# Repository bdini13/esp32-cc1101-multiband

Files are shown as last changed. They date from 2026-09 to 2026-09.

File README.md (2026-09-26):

# ESP32 + CC1101 Multiband

A custom USB-C development board combining an **ESP32-WROOM-32E-N8** with an
integrated **CC1101** sub-GHz radio, software-selected RF paths, and a vertical
SMA antenna connector at the opposite end from USB-C.

**Rev A3 · Fully connected review candidate · Not approved to manufacture or sell**

The aim is to replace a separate ESP32 board, CC1101 breakout and jumper wires
with one purpose-built PCB. The first intended build is **five assembled
engineering prototypes**, after the pre-order checks are complete. Possible
product sales are a future option, not a launch announcement.

## Current design

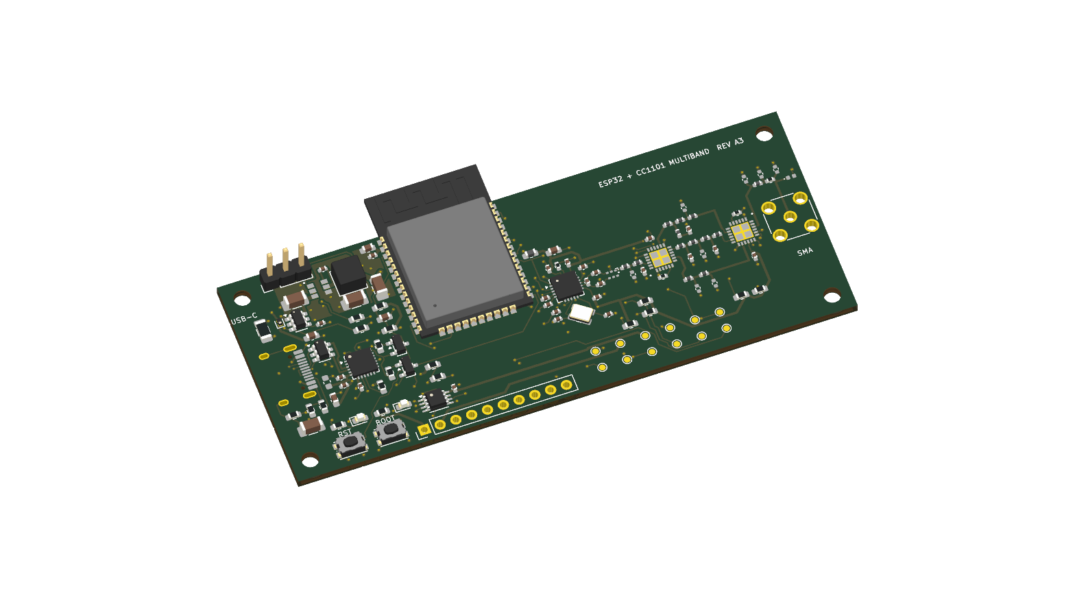
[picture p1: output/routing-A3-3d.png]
A3 angled KiCad routed-board render, USB area left and SMA footprint right


*KiCad design render—not a photograph of a built board. USB, SMA and some
RF parts lack complete 3D bodies. Their absence in the image does not mean
they were removed from the design.*

<details>
<summary>Top view and experimental routing</summary>

A3 top-copper routing candidate

*The routing image is a separate experimental candidate, not the main placement
file or a fabrication package. Bottom and inner routes are not shown here.*

</details>

[Schematic SVG](output/svg-A3/esp32-cc1101-multiband.svg) ·
[Latest design report](reports/autonomous-refinement-A3-2026-09-26.md) ·
[Draft BOM](hardware/bom-draft.csv) · [Roadmap](ROADMAP.md)

Latest work: A3 replaces the power supply and RF switches, completes routed
connectivity, adds safe RF boot sequencing and proposes all populated parts.
See [engineering decisions and first-power instructions](docs/06-A3-prototype-engineering.md)
and the [pre-order blocker report](reports/preflight-A3.json). The crystal was
relocated and rerouted: all 180 artifact checks and six route screens now pass.
Independent/supplier reviews remain pending. No hardware has been tested.
Do not order historical A2 files.

## Building blocks and design inputs

### ESP32-WROOM-32E-N8 — controller and 2.4 GHz connectivity

<a href="https://www.espressif.com/en/products/modules/esp-">
  Manufacturer reference image of the stock ESP32-WROOM-32E module
</a>

*Stock module reference image: Espressif, linked from the manufacturer's site.
This is not a photo of the custom board or a guarantee of the N8 marking.*

The actual component is an Espressif module, not an entire stock development
board soldered onto another PCB. The selected N8 variant has 8 MB flash; its
ESP32 provides a dual-core processor, 2.4 GHz Wi-Fi and Bluetooth. Its PCB
antenna is separate from the sub-GHz SMA path. The antenna section extends
beyond the custom base board to preserve its keepout.
[Module datasheet](https://documentation.espressif.com/esp32-wroom-32e_esp32-wroom-32ue_datasheet_en.html).

Power/programming uses ESP32 development-board conventions: USB-to-UART,
automatic reset/boot control and manual BOOT/RESET buttons. This is not a
pin-compatible clone of a particular commercial DevKit.
[Espressif ESP32-DevKitC reference](https://docs.espressif.com/projects/esp-dev-kits/en/latest/esp32/esp32-devkitc/user_guide.html).

### Texas Instruments CC1101 — sub-GHz transceiver

<a href="https://www.ti.com/product/CC1101">
  Texas Instruments representative RGP 20-pin QFN package image for CC1101
</a>

*Representative package image: Texas Instruments. This is the IC package,
not a complete CC1101 antenna module; package markings may differ.*

The PCB integrates **CC1101RGPR** directly, with its crystal, bypass capacitors,
balun, switches and matching/filter components. TI specifies tuning ranges
of 300–348, 387–464 and 779–928 MHz. That does **not** make every frequency or
antenna equally usable or establish this board's RF performance.
[CC1101 product information and datasheet](https://www.ti.com/product/CC1101).

The separate [Amazon CC1101 module](https://a.co/d/01gplHzS) supplied by the
owner was a functional starting point. Its exact internal circuit and advertised
four-band performance have not been independently verified here. The switched
RF topology and initial component values also reference the
[M5Stack Cap CC1101 schematic](https://docs.m5stack.com/en/cap/Cap_CC1101).
This is a different implementation, not an endorsed M5Stack product.

### Supporting parts currently selected

| Function | Current design choice |
|---|---|
| USB-C | HRO TYPE-C-31-M-12, USB 2.0 connection |
| USB-to-UART | Silicon Labs CP2102N-A02-GQFN24 |
| 3.3 V regulator | AP63203WU-7 buck, XAL4030 4.7 uH inductor |
| USB startup / UART isolation | TPS22918, SN74LVC2G125; J4 ships unjumpered |
| Radio reference | Abracon ABM8, 26 MHz; load requires validation |
| RF selection | Two pSemi PE42442A-Z SP4T switches; three paths used |
| RF balun | B0310J50100AHF |
| Antenna connector | Amphenol 132134, vertical standard SMA female, 50 ohm |

See [third-party notices](THIRD_PARTY_NOTICES.md) for provenance, image credits
and license boundaries. Parts remain subject to sourcing, footprint and assembly
approval; the BOM is not an approved shopping list.

## Planned capabilities and features

| Feature | Planned behavior | Status |
|---|---|---|
| Four target bands | 315 / 433 / 868 / 915 MHz, one selected at a time | Not RF-validated |
| Software band switching | GPIO-operated RF switches; no DIP switches | Circuit present; firmware isolation only |
| Three RF branches | Dedicated 315 and 433 paths; shared 868/915 path | Matching, loss and isolation unmeasured |
| Single sub-GHz SMA | Vertical connector opposite USB-C | Placed; mechanical approval pending |
| USB-C power/programming | 5 V input, USB-to-UART flashing/logging | Captured; not bench-tested |
| Wi-Fi / Bluetooth | Available through the ESP32 module | Application integration planned |
| Developer controls | BOOT, RESET, LEDs and test pads | Included in draft |
| Expansion | Optional DNP 10-pin header | Included in draft |
| PCB | 90 × 36 mm base, four layers, nominal 1.6 mm | Stackup/impedance release pending |
| Safe bring-up | RF paths isolated; no transmit command | Implemented in initial firmware |

Band switching changes the **hardware path**. Future firmware must also set the
radio frequency/modem registers and operating limits. One CC1101 cannot listen
on all four bands simultaneously. Use an antenna suitable for the selected
band; a shared SMA does not imply a universal antenna.

There is no native USB, USB-PD, battery charger, finished RF application or
guaranteed protocol compatibility in this revision.

## What has actually been checked?

Snapshot: **2026-09-26**, KiCad 10.0.6. Design-file checks, not lab results.

| Check | Result |
|---|---|
| Schematic ERC | 0 reported violations |
| Main placement seed DRC | 0 violations; 283 unconnected items (not the routed board) |
| Targeted artifact checks | **180 / 180 passing** on refined candidate / explicit seed checks |
| Added route screens | **6 / 6 passing**; oscillator routing, cross-layer clearance and modeled DC drops |
| Separate A3 routed candidate DRC | **0 violations; 0 unconnected items** |
| Fresh schematic / routed PCB comparison | Every numbered pad net, value and footprint name matches |
| Layer constraints | No signal traces on In1; RF/clock top-only; documented USB crossover |
| Candidate power routing | Main rails explicitly routed; 60 narrower branch/neck segments listed; critical copper paths quantitatively screened |
| Parts selection | **94 / 94** populated positions have proposed exact parts; sourcing unapproved |
| Physical boards tested | **None** |

Zero reported violations does not prove working or compliant hardware. A3's
power redesign addresses the earlier LDO heat problem and the new switches
cover the target bands in their specified frequency range. Actual power
sequencing, temperature, impedance, matching and crystal startup/frequency
remain unmeasured. C21 and U5 contain in-pad vias requiring filled/capped
processing; supplier DFM confirmation is mandatory. USB power must be
configured before fitting J4, and full combined Wi-Fi/radio load is not approved.

[Raw reports](reports/) · [Verification checklist](docs/04-verification-plan.md) ·
[Power, routing and RF validation plan](docs/06-A3-prototype-engineering.md)

## Roadmap

1. **Design capture — substantially complete:** schematic, placement, draft
   BOM, local footprints, bring-up firmware and automated checks.
2. **Prototype review — in progress:** routed connectivity and proposed parts
   complete; crystal, power, mechanical, supplier and independent review open.
3. **Five-board build — not ordered:** reviewed fabrication and assembly files,
   then separately approved prototype procurement.
4. **Bench and RF tuning — not started:** power/temperature, USB, crystal,
   per-band matching, harmonics and receive performance.
5. **Firmware/application — planned:** validated receive-first operation,
   controlled band changes and deliberately configured regional limits.
6. **Possible product — undecided:** hardware revision, compliance, enclosure,
   test fixtures, sourcing, support and commercial terms.

The [detailed roadmap](ROADMAP.md) uses acceptance criteria, not promised dates.
There is no release date, sales price, preorder or claim of certification.

## Open the project

Open `hardware/esp32-cc1101-multiband.kicad_pro` in **KiCad 10** for the main
placement seed and schematic. Open `hardware/A3-routing-candidate.kicad_pro`
separately for the unapproved routing experiment. Do not order either one.

Python generators are the editable source for this checkpoint. **Regenerating
placement overwrites the generated board; preserve manual routing first.**
See [rebuild instructions](hardware/REBUILD.md) and
[firmware instructions](firmware/bringup/README.md).

Initial firmware resets the CC1101, checks repeated PARTNUM/VERSION reads and
stable IDLE state, and logs explicit failures. It does not configure a receiver
or transmitter and has not run on physical hardware. Passing digital diagnostics
is not proof of authenticity or RF qualification.

## AI disclosure

This project is developed with substantial assistance from **OpenAI Codex**
under the owner's direction. AI assisted with component research, schematic/PCB
generators, footprints, experimental routing, firmware, documentation and review.
Design images are KiCad renders/exports, not AI-generated product photographs.

AI output and automated checks can contain errors. They are not independent
engineering approval, bench validation or regulatory certification. No physical
prototype has been completed. Qualified human electrical/RF review remains a
release gate. See the [full AI disclosure](AI_DISCLOSURE.md).

## Licensing, commercial plans and safety

This initial publication uses the **[Public Review License](LICENSE)**:
non-commercial study/private evaluation is permitted; manufacturing, product
sales and other uses beyond its limited permissions require written permission.
Commercial rights are reserved while the owner's plans are undecided. This is
**source-available, not open-source/open hardware**. Third-party terms are
separate; see [notices](THIRD_PARTY_NOTICES.md). Obtain legal advice before
relying on the custom license for a commercial launch.

Use only with equipment and signals you own or are authorized to test. Tunable
frequencies are not automatically permitted transmit frequencies. Final use and
sale require applicable RF, EMC, product-safety and other compliance work. This
prototype is not for safety-critical applications. No manufacturer named here
endorses the project.

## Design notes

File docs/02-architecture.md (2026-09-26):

# A3 architecture

Current circuit source: `hardware/generate_schematic.py`. Detailed decisions,
sources and limits: [A3 engineering notes](06-A3-prototype-engineering.md).
Historical A1/A2 files are not interchangeable with A3.

## Power and programming

USB-C 5 V passes through a 750 mA PTC and transient protection. The CP2102N
internal regulator powers only its USB-side logic (`+3V3_USB`). Its SUSPENDb
output, via an initially unfitted J4 shunt, enables TPS22918. That switch
soft-starts the AP63203 3.3 V buck and the ESP32/radio supply. SN74LVC2G125
isolates the UART while the main rail is off. Manual BOOT/RESET and the
two-transistor DTR/RTS auto-programming circuit are retained.

J4 ships open. Configure/read back a bus-powered 500 mA USB descriptor before
using AUTO (1–2). EXT (2–3) needs a separately verified regulated 5 V source.
There is no USB-PD negotiation, battery support or external-power source ORing.
The buck's IC rating is not a board/USB current rating. High combined Wi-Fi/RF
loads are not approved. USB suspend shuts down the main rail.

The RF rail passes through a ferrite and local bypass capacitors. CC1101
DGUARD is supplied, not grounded. A 26 MHz four-pad crystal provides its clock;
load capacitance and oscillator startup/frequency need bench verification.
The refined diagonal placement meets both original distance targets and
reduces the longest clock route to approximately 3.99 mm.

## Radio path

CC1101 differential RF → broadband balun → PE42442 input selector → one of
three filter branches → PE42442 output selector → tuning network → vertical
standard SMA female. Branches target 315, 433 and shared 868/915 MHz.

Both switches use 10 kohm external control pullups and boot in 111 isolation.
Their fourth RF ports are terminated in 49.9 ohm. U4's outer branches are
reversed physically, with independent GPIO controls; see the
[pin map](03-pin-map.md). Firmware currently performs digital checks only,
keeps every path isolated, and provides no RX/TX command.

Reference-derived matching values are starting points. The CC1101 tuning
range alone does not establish a four-band antenna match, sensitivity, range
or emissions compliance. Prototype RF tuning and measurement are required.

## Mechanical and layout

90 × 36 mm four-layer base, nominal 1.6 mm. USB-C opens at the left end;
SMA is vertical at the right. The ESP32-WROOM-32E-N8 antenna overhangs the
top edge. Proposed L2 is uninterrupted ground; no signal routing is allowed
there. Main RF and oscillator traces stay on top. USB has a short bottom-side
connector crossover. Actual impedance requires fabricator confirmation.

Two in-pad vias require filled/capped processing, not ordinary open drills:
C21 at (46.5,18.9) mm and U5 exposed pad at (16,19.4) mm. All coordinates
are KiCad board coordinates. Supplier review must also inspect nearby vias,
paste coverage, component orientation and connector fit.

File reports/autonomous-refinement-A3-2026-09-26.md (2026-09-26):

# A3 autonomous layout refinement — 2026-09-26

The remaining crystal placement failure was resolved in the routed candidate,
without weakening its 3.5 mm limit. No part, pin assignment, RF filter value,
firmware operating mode or licensing term changed. No board was ordered.

## What changed

Y1 moved to (50.2,23.23) mm and -37.5 degrees. C31/C32 moved outward;
clock, ground, power and nearby digital traces were rebuilt. Both clocks
remain top-side and via-free. The earlier board is preserved in
`hardware/routing/A3-before-crystal-refinement.kicad_pcb`, with a source-hash
guard in the refinement script. The main placement/critical-route files remain
upstream seeds; the final routed candidate is the current layout authority.

| Metric | Before | Refined candidate |
|---|---:|---:|
| U2.8 to Y1.1 straight-line distance | 2.195 mm | 3.468 mm |
| U2.10 to Y1.3 straight-line distance | 4.478 mm | 3.479 mm |
| Q1 routed pin-center to crystal-center length | 2.538 mm | 4.299 mm |
| Q2 routed pin-center to crystal-center length | 6.887 mm | 3.994 mm |
| Longest clock route | 6.887 mm | 4.299 mm |
| Artifact checks | 179/180 | 180/180 |
| Added route screens | 4/6 (retrospective) | 6/6 |

This tradeoff lengthens Q1 while reducing Q2 and the total clock-route length.
The near-diagonal crystal is deliberate, not an assembly rotation error; the
assembler must honor its actual angle. Existing courtyard and clearance rules
were retained. Crystal load values remain starting values, not a measured tune.

## New checks beyond native DRC

TI advises keeping sharp-edged digital routing away from the oscillator input
and from beneath the Q1 crystal pad. The new screen projects digital traces
and vias from **every copper layer** onto the full Q1 rectangular pad envelope;
it conservatively ignores rounded corners and does not waive the screen
because a ground plane lies between layers.
[CC1101 datasheet](https://www.ti.com/lit/ds/symlink/cc1101.pdf).

The first trial caught CSn/GDO2 under this envelope. They and a nearby RF
selector route were moved. Minimum projected clearance is now **0.2079 mm**,
against a project screen of 0.20 mm. New tests deliberately inject a bottom
trace under the pad and verify detection. This is a geometry screen, not a
coupling/noise simulation. Other oscillator/RF review and bench tests remain.

The route model also follows actual trace/via connectivity to estimate DC
resistance. It assumes copper at 80 C, 80% of target layer copper thickness,
and 20 um via plating; each layer transition is charged a full 1.6 mm barrel.
These are explicit modeling assumptions, not supplier guarantees.

| Copper path | Independent screening load | Modeled drop |
|---|---:|---:|
| Buck output L1.2 → ESP32 supply | 0.5 A | 7.423 mV |
| USB A4 → fuse | 0.5 A | 14.331 mV |
| USB A9 → fuse | 0.5 A | 20.464 mV |
| Fuse → main load switch | 0.5 A | 4.667 mV |
| Load switch → buck input | 0.5 A | 2.506 mV |
| RF bead output → output RF switch | 0.1 A | 13.316 mV |

The model omits components, contacts/pad spreading, cable and ground-return
resistance. It follows the least-resistance single path, ignoring parallel
paths. It is not a thermal, ampacity, transient, USB-compliance or RF-noise
analysis. Loads in different rows must not be added and presented as an
approved simultaneous operating mode. See all 14 paths and six project screens
in [the current model](route-margins-A3.json) and the
[retrospective baseline](route-margins-A3-before-crystal-refinement.json).

## Verification and remaining boundary

- Native candidate DRC: **0 violations / 0 unconnected items**.
- Fresh schematic/PCB parity: passes; schematic connectivity is unchanged.
- Artifact audit: **180/180**, now checks the final routed geometry; only the
  two initial-stitching checks explicitly use the placement seed.
- Route screens: **6/6**. Seven new geometry/resistance/fault-injection tests pass.
- Eight preflight tests pass. Fresh preflight reruns route metrics and hashes
  generator/check code plus firmware sources, as well as hardware artifacts.
- Existing 17 diagnostic cases, RF-boot tests and connectivity fault tests
  are rerun; firmware has not been flashed or tested on hardware.

Preflight still requires six unsigned independent/supplier review categories.
Filled/capped C21 and U5 vias remain necessary. Matching, oscillator startup,
frequency accuracy, USB sequencing, thermal behavior and RF performance are
unmeasured. No human review was marked approved by the agent, and no
fabrication package or purchase order was created.

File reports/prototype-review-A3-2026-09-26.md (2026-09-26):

# A3 prototype-review checkpoint — 2026-09-26

**Historical pre-refinement snapshot.** The crystal failure below has since
been resolved without changing its threshold. See the
[current refinement report](autonomous-refinement-A3-2026-09-26.md).

**Fully connected review candidate, not an approved order or proven radio.**
The owner's five-board prototype goal is unchanged. No hardware, quote, order,
human signature or measurement is represented by this checkpoint.

## Problems addressed

- Replaced the heat-constrained LDO with AP63203, a rated 4.7 uH inductor and
  higher-voltage/larger MLCCs selected after inspecting DC-bias curves.
- Added USB-side independent power, enumeration-controlled TPS22918 startup,
  J4 commissioning control and powered-off-protected UART buffers. Documented
  the USB current limitation instead of implying a buck negotiates power.
- Replaced the previous low-band-limited RF switches with PE42442 SP4Ts;
  checked manufacturer pin/land drawings, terminated unused RF4 ports and
  gave U4 independent selectors to avoid RF crossings.
- Corrected safe boot to five HIGH controls with 10 kohm pullups. Added
  preload/disable-order tests; transmit and receive commands remain absent.
- Explicitly routed RF, oscillator, USB, converter and main power before
  digital routing. Finished the remaining nets without suppressing DRC errors.
- Proposed exact parts for all 94 populated positions, plus a separate loose
  power-arm shunt accessory. There are 117 schematic footprints / 121 PCB
  footprints including four mounting holes; DNP parts and bare pads are not
  populated BOM purchases.
- Added fresh schematic/PCB comparison and fault-injected tests that reject
  wrong net, value, footprint name and missing component. A clean stale
  netlist is not accepted as the only connectivity evidence.

## Evidence

| Check | Result |
|---|---|
| Fresh schematic ERC | 0 violations |
| Routed A3 native DRC | 0 violations / 0 unconnected items |
| Fresh schematic to candidate comparison | PASS |
| Placement-seed native DRC | 0 violations / 283 unconnected items, intentionally unrouted |
| Artifact audit | 179/180; one crystal placement screening failure retained |
| Routing-layer constraints | 0 violations; no In1 signal tracks |
| Digital diagnostic tests | 17 fault-injection scenarios pass |
| RF boot tests | Pin map, preload order, disable-first and re-isolation pass |
| Preflight tests | 7 pass |
| Connectivity fault-injection tests | 4 malformed temporary boards rejected |
| ESP32 firmware build | PASS; 275645 bytes flash / 21576 bytes RAM |
| Physical boards tested | None |

The build used espressif32 7.1.3, Arduino framework
4.20017.260907+sha.dcc1105b, esptool 2.41100.260830 and Xtensa toolchain
8.4.0+2021r2-patch5. Project settings explicitly select 8 MB flash and
default_8MB partitions; the generic platform banner still says 4 MB.

KiCad top-copper, ground-plane, schematic and 3D exports were visually
inspected. The ground plane has no routed signals and appears continuous
beneath the circuitry; that is not an EMC/impedance certification. Missing
USB/SMA/custom-IC 3D bodies are disclosed in the README.

## Open items, with concrete closure criteria

1. **Crystal:** U2.10 to Y1.3 is 4.478 mm straight-line versus the retained
   3.5 mm screening target. The route is approximately 6.888 mm, plus its
   load-cap branch (whole net 8.142 mm). Q1 whole-net copper is 4.545 mm.
   The 3.5 mm limit is a project screening target, not a quoted TI maximum.
   An RF reviewer must assess relocation/clock loading before release; measure
   cold starts, frequency and supply/temperature sensitivity on the prototype.
   The check has deliberately NOT been weakened or silently waived.
2. **Power:** main paths are explicitly routed, but 62 branch/neck segments
   below 0.40 mm remain listed for current/voltage-drop review. Confirm USB
   configuration and J4 procedure, suspend/resume, back-power leakage, load
   steps, fuse drop and converter temperature. The full combined Wi-Fi/radio
   load can exceed 500 mA input at low cable-end voltage; it is not approved.
3. **RF:** approve matching/layout for prototype tuning, then measure each
   selected path with a VNA and conducted receive/spectral equipment. The
   switches' specified frequency coverage does not validate the whole board.
   Current firmware tests digital access only, not usable multiband RX/TX.
4. **Fabrication/assembly:** confirm exact stackup, RF/USB impedance, all
   small vias and pad-adjacent drills. C21.1 (46.5,18.9 mm) and U5 exposed
   ground pad (16,19.4 mm) require resin-filled/copper-capped vias. Confirm
   paste coverage, footprints, USB/SMA fit and real part availability.
5. **Independent review:** a qualified electrical/RF reviewer must approve
   the exact candidate hashes and documented prototype risks. No AI-generated
   result substitutes for their review or the subsequent bench tests.

See [fresh preflight](preflight-A3.json), [routing audit](routing-audit-A3.json),
[engineering calculations](engineering-budget-A3.json), and the
[detailed commissioning/acceptance plan](../docs/06-A3-prototype-engineering.md).
Preflight remains BLOCKED. No fabrication package was generated and no order
was placed. A1/A2 artifacts are historical; do not mix their firmware or parts
with A3. The existing project license is unchanged.

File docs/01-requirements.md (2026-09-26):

# Rev A Requirements

Status: initial requirements captured 2026-09-20; updated for A3 2026-09-26.
These are target requirements, not assertions that the draft already satisfies them.

## Functional requirements

1. Use an ESP32-WROOM-32E module with 8 MB flash.
2. Integrate one TI CC1101 transceiver directly on the main PCB.
3. Support software selection of 315, 433, and 868/915 MHz RF matching paths.
4. Use one standard 50-ohm SMA female antenna connector.
5. Place the SMA connector vertically at the short end opposite USB-C.
6. Provide USB-C power, serial programming, logging, and automatic bootloader
   entry.
7. Provide physical RESET and BOOT buttons.
8. Provide a power LED and a firmware-controlled status LED.
9. Expose spare GPIO, 3V3, 5V, and ground on a 2.54 mm expansion header.
10. Include accessible test points for all power rails, UART, SPI, CC1101 GDO
    signals, and RF-switch control signals.

## Electrical requirements

- USB input: nominal 5 V.
- Logic and radio rail: 3.3 V.
- A3 uses AP63203 fixed 3.3 V buck, rated 2 A as an IC, not as a board.
  Actual board current is limited by USB source capability, voltage drop,
  fuse derating and measured thermal behavior; full simultaneous Wi-Fi/RF
  load is not yet approved. Configure the USB descriptor with J4 open first.
- USB-C CC1 and CC2: independent 5.1 kohm pull-down resistors.
- USB D+ and D-: ESD protected and routed as a differential pair.
- ESP32 EN: RC power-on reset plus USB-UART automatic reset control.
- CC1101: dedicated local decoupling at every supply pin.
- RF switches: five 10 kohm pullups select the isolated `111` state during boot;
  firmware must keep the CC1101 idle during path changes.

## Mechanical requirements

- Nominal board outline: 90.0 mm x 36.0 mm.
- Four-layer stackup with uninterrupted internal ground plane.
- USB-C centered on one 36 mm edge.
- Straight through-hole SMA centered on the opposite 36 mm edge.
- Four M2.5 mounting holes, final coordinates subject to component clearance.
- ESP32 module PCB antenna located at a board edge with the Espressif keepout
  observed on every copper layer.
- A1 placement: module antenna tip projects 6.45 mm beyond the base PCB.
  Allow at least 42.45 mm total width before enclosure/RF clearances.
- Maintain maximum practical separation between the ESP32 antenna and the
  CC1101 RF section/SMA connector.

## User-facing behavior

- Power-up state: CC1101 idle, transmit disabled.
- Firmware band API: `315`, `433`, `868`, or `915`.
- Selecting a band first idles the radio, then changes the RF switches, waits
  for settling, loads band-specific CC1101 registers, and calibrates.
- A3 switch state `111` is the all-paths-isolated safe state; `000` selects RF4.
- Transmit operations require an explicit region profile and compatible
  antenna confirmation in production firmware.

## Prototype quantity

- Five assembled Rev A boards.
- Optional spare boards and band-appropriate antennas need a separately
  approved quote; no purchase is authorized by this requirements document.

## Explicitly out of scope for Rev A

- Battery charging or battery connector.
- Display, keypad, audio, NFC, SD card, or external power amplifier.
- Weatherproofing or production enclosure.
- FCC/CE certification.
- Simultaneous operation on multiple sub-GHz bands.

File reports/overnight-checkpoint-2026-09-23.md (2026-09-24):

# A2 overnight checkpoint — 2026-09-23

Status: saved engineering progress, **not ready for an order**. No PCB topology,
placement or routing was changed in this checkpoint. A2 images remain current.

## Completed

- Replaced the firmware's permissive identity check, which accepted an all-zero
  SPI response, with repeated exact identity checks and stable IDLE detection.
- Added bounded waits, distinct failure reporting, transaction cleanup, the TI
  manual-reset preamble, and a restricted API with no RX/TX/path-selection entry.
- Added 17 host fault-injection scenarios and six pre-order-check unit tests.
  All pass. Host tests do not validate GPIO waveforms or physical hardware.
- Successfully built the ESP32 firmware: 21,576 bytes RAM, 275,569 bytes flash.
- Re-ran the design audit: 115/115 pass. Fresh native KiCad checks: ERC zero
  violations; candidate DRC zero violations and **23 unconnected items**.
- Added a fresh-check preflight command, explicit pending review records and
  input SHA-256 fingerprints. It reports **BLOCKED**, as intended.
- Corrected the pin-map claim that GPIO4 was a boot-strapping GPIO.

Build environment: PlatformIO espressif32 7.1.3, Arduino framework
4.20017.260907+sha.dcc1105b, Xtensa toolchain 8.4.0+2021r2-patch5,
esptool package 2.41100.260830. Platform version pinned; no device flashed.

## Power replacement screening

AP63203WU-7 is a candidate, **not substituted into A2**. It is a fixed-3.3 V
buck with a 3.8–32 V input range. The manufacturer's starting circuit uses a
3.9 uH inductor, 10 uF input capacitance, two 22 uF output capacitors and a
100 nF bootstrap capacitor. TSOT26 pins are FB1, EN2, VIN3, GND4, SW5, BST6.
Its switching behavior requires a new hot-loop layout, shielded-inductor
selection, capacitor derating, noise review and transient testing. It does not
solve USB input-current permission. The PDF skill guided visual inspection of
manufacturer pin/ordering drawings before deciding against an unverified swap.
[Diodes datasheet](https://www.diodes.com/assets/Datasheets/AP63200-AP63201-AP63203-AP63205.pdf).

## RF replacement screening

PE42430 is another candidate, **not a drop-in replacement**. Its specified RF
range extends down to 100 MHz, but it has three control inputs and derives
power from them; control-high minimum is 3.0 V. That is not a verified direct
ESP32 GPIO interface. Its pinout, ground paddle, startup isolation, logic drive
margin and routing would all need redesign/review. Retaining the existing
switch in the saved draft does not resolve its low-band performance risk.
Visual inspection of the manufacturer's pinout and operating-range table
prevented treating it as an interchangeable eight-pin part.
[pSemi datasheet](https://psemi.com/pdf/datasheets/pe42430ds.pdf).

## Reproduce the order-blocker check

```sh
python3 tools/test_preflight.py
python3 tools/preflight.py --kicad-cli kicad-cli --output reports/preflight-A2.json
```

The last command intentionally exits **2** when blocked; 1 indicates execution
failure. It runs new ERC and candidate DRC, then checks BOM selection and six
review records. Even with all gates closed, it only reports that separate owner
order approval is needed. It cannot place orders or export fabrication files.
The candidate has a separate basename, so schematic parity is not automatically
checked by this command; independent connectivity review remains mandatory.
Review records are declarations, not authenticated engineering sign-offs.

## Remaining before the five-board prototype order

1. Choose/review power and low-band RF solutions; then revise the circuit/layout.
2. Finish critical routing and the 23 connections; review 35 narrow power
   segments, USB pair geometry, RF impedance and return paths.
3. Select the remaining 18 populated BOM positions and approve sourcing/assembly.
4. Complete mechanical and independent electrical/RF review, then obtain a quote
   and separate purchase approval. Bench/RF validation follows the prototype build.

See the [machine-readable fresh-check snapshot](preflight-A2.json) and
[roadmap](../ROADMAP.md). There are still no physical measurements or built boards.

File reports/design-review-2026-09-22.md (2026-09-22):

# PCB design review — 2026-09-22

Disposition: **requires schematic and placement corrections before routing or manufacture.**

Reviewed the saved KiCad schematic, XML netlist, PCB pad assignments, generator
sources, BOM, custom RF footprints, and existing placement renders. Reran ERC
and DRC against the saved files without regenerating or modifying the design.
Manufacturer PDF drawings were checked visually where available, including the
balun outline and the previously captured M5Stack reference schematic.

## Confirmed electrical and mechanical defects

### 1. P1 — CC1101 DGUARD is connected to ground

`hardware/generate_schematic.py:287` assigns U2 pin 18 to GND. The saved netlist
and PCB both contain that connection. Pin 18 is DGUARD, a supply input, not a
ground pin. TI's pin table identifies it as a power-supply connection; the
M5Stack reference used for this project connects it to 3.3 V with the other
CC1101 supply pins. Correct to the appropriate RF supply and review all supply
connections and bypass capacitors. Functional radio operation cannot be assumed
with this pin grounded.

Source: [TI CC1101 datasheet, Table 19 and application circuits](https://www.ti.com/lit/ds/symlink/cc1101.pdf).

### 2. P1 — Balun footprint pad numbering is mirrored

`hardware/lib/esp32_cc1101.pretty/TTM_B0310J50100AHF.kicad_mod:24` places
1-2-3 across the upper row and 6-5-4 across the lower row. This copies the
manufacturer's explicitly labeled BOTTOM VIEW into a front-side PCB footprint.
With the same vertical orientation, the top view must have 3-2-1 across the
upper row and 4-5-6 across the lower row. The physical orientation marker must
also agree with the top view. Rotation alone does not correct a reflection.

Rebuild the footprint from a top-view projection and recheck the assembly
orientation. As drawn, the grounded pad 2 and unconnected pad 5 prevent a simple
180-degree rotation of the real part from restoring the intended connections.

Source: [TTM B0310J50100AHF Rev F, page 1 outline and pin table](https://cdn.ttm.com/repository/products/wireless-xinger/balun-transformers/B0310J50100AHF/B0310J50100AHF.pdf).

### 3. P1 — USB-C receptacle faces into the board

`hardware/generate_pcb.py:62` places J1 at (4.8, 18.0), rotation +90 degrees.
The installed KiCad USB4105 footprint marks its intended PCB edge at local
y=+3.675 mm. On the saved board that line is at x=8.475 mm, while the board's
left edge is x=0. The solder tails lie near x=1.12 mm. Thus the mating opening
faces the electronics instead of the outside edge. Rotate and reposition the
connector with its annotated mating edge aligned to the left board edge, then
redo USB protection placement and mechanical clearance.

Evidence: saved PCB geometry and the installed
`Connector_USB:USB_C_Receptacle_GCT_USB4105-xx-A_16P_TopMnt_Horizontal`
footprint's `PCB Edge` annotation. The previous render approval missed this.

### 4. P1 — CP2102N VBUS sensing bypasses the required divider

`hardware/generate_schematic.py:157` connects U5 pin 8 directly to the protected
5 V rail. Silicon Labs requires a resistor divider or equivalent for this
sense input in both bus-powered and self-powered configurations, including
when VIO is not yet powered. Its reference circuit uses 22.1 kohm above the
sense node and 47.5 kohm to ground. Pin 7 VREGIN is a separate power input;
do not apply the divider to the power input.

The power arrangement also needs a complete bypass and sequencing review:
VIO uses the external 3.3 V supply while VDD uses the internal regulator. C3 is
the only capacitor on VDD, and C4's VIO pad is 7.33 mm from the IC pad. Check
the manufacturer's per-power-pin capacitor requirements and VIO <= VDD limit.

Source: [Silicon Labs CP2102N datasheet, sections 2.1, 2.3 and Table 3.1](https://www.silabs.com/documents/public/data-sheets/cp2102n-datasheet.pdf).

### 5. P2 — Both indicator LEDs are reversed

`hardware/generate_schematic.py:247` and `:255` connect LED pin 1 to the
positive resistor node and pin 2 to ground. The embedded KiCad Device:LED
symbol defines pin 1 as K (cathode) and pin 2 as A (anode). Both LEDs are
therefore reverse-biased in their intended operating state and will not light
normally. Swap the electrical assignments and preserve a consistent assembly
polarity mark.

### 6. P1 — D2's proposed part does not fit its footprint

`hardware/bom-draft.csv:26` selects PESD5V0S1UL, but
`hardware/generate_schematic.py:122` assigns SOD-323. Nexperia specifies
DFN1006-2 / SOD882 for that exact part. Select a matching part/footprint pair.
Also use a symbol that communicates its unidirectional polarity; the current
generic D_TVS symbol has anonymous A1/A2 terminals.

Source: [Nexperia PESD5V0S1UL datasheet, pinning and ordering information](https://assets.nexperia.com/documents/data-sheet/PESD5V0S1UL.pdf).

## Placement and performance risks requiring revision

### 7. P1 — Radio bypass capacitors are remote; switch bypass capacitors are absent

The C21-C25 row in `hardware/generate_pcb.py:102` is arranged above U2 rather
than around its supply pins. For U2 pins 4/9/11/14/15, the nearest capacitor
supply-pad center is respectively 5.53/6.89/6.09/4.62/4.13 mm away. These are
straight-line distances before routing. Y1's pads are about 5.1 mm from the
oscillator pins, and the RBIAS resistor pad is 6.21 mm from its pin.

Neither U3 nor U4 has its own local bypass capacitor. Even C25 is 12.15 mm
from U3 VDD and 21.86 mm from U4 VDD. The captured M5Stack reference includes
one 100 nF capacitor at each switch. Add local switch bypassing and rebuild the
CC1101 placement around short supply, oscillator and ground-return paths.

The differential RF paths also need coordinated orientation: C40/BAL_N is
above C41/BAL_P, while the current balun puts BAL_N below BAL_P. Correcting the
mirrored footprint and arranging these parts together should precede routing.
The RF switches' common/branch pad locations must likewise drive placement.

Source: [TI CC1101 datasheet, sections 7.6 and 7.8](https://www.ti.com/lit/ds/symlink/cc1101.pdf).

### 8. P2 — ESP32 antenna placement does not match the earlier description

`hardware/generate_pcb.py:65` places the module at y=15.5 mm. Its antenna
section lies approximately between y=2.75 and y=8.94 mm, entirely over the
rectangular base PCB. It does not overhang the edge. The footprint keepout
being empty is helpful but does not establish RF performance or satisfy the
stated overhang arrangement. Move the module or design a suitable board cutout.

Source: [Espressif module placement guidance](https://docs.espressif.com/projects/esp-hardware-design-guidelines/en/latest/esp32/pcb-layout-design.html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).

### 9. P2 — Regulator thermal capability is unproven

U6 is the conventional DBV SOT-23-5 TLV75733P, not the exposed-pad package.
At an illustrative continuous 300 mA load, a 5 V to 3.3 V LDO dissipates
approximately 0.51 W. TI lists 231.1 C/W for DBV on its JEDEC board and
100.8 C/W in the EVM comparison, showing strong layout dependence. These are
screening figures, not predicted temperatures for this unrouted PCB.
Calculate the actual Wi-Fi/radio load profile and thermal margin before
accepting this package. Its 1 A current rating alone does not establish that
the board can dissipate the heat.

Source: [TI TLV757P datasheet, thermal information and power dissipation](https://www.ti.com/lit/ds/symlink/tlv757p.pdf).

## Verification results and limits

- Fresh ERC: 0 violations. U2 and the RF switches use generic connector
  symbols with passive pins, so ERC cannot meaningfully validate their power
  pin functions. Replace them with verified functional symbols.
- Fresh DRC: 4 hole-clearance **errors**, each 0.1944 mm actual versus
  the configured 0.2500 mm minimum, internal to J1. The earlier description
  called these warnings; the current project classifies them as errors.
- 206 unconnected items; 0 routed tracks/vias; 0 board-level copper zones.
  Exposed-pad holes exist inside footprints, but no ground plane connects them.
- No reported current pad shorts, general clearance violations or courtyard
  overlaps. This does not establish electrical correctness or RF suitability.
- Four copper layers and 1.6 mm overall thickness are specified, but no actual
  fabricator dielectric stackup or routed impedance-controlled geometry exists.
- J2 uses a vertical SMA footprint on the opposite end from J1, consistent with
  the intended connector arrangement. The orderable SMA part remains TBD.
- The documented GPIO truth table agrees with Infineon's table when SW0=V2
  and SW1=V1. This verifies logic, not the complete RF design or assembly.
- The BOM omits many ordinary resistors and capacitors and is not an assembly
  BOM. Exact RF part series, crystal and other unspecified items remain open.
- BGS13SN8's tabulated RF performance starts at 698 MHz; the listed broader
  frequency range alone is not a guarantee of 315/433 MHz performance. Verify
  those lower bands experimentally or obtain supporting characterization.

Source: [Infineon BGS13SN8 datasheet, Tables 4 and 9](https://www.infineon.com/assets/row/public/documents/24/49/infineon-bgs13sn8-datasheet-en.pdf).

## Recommended correction sequence

1. Correct DGUARD, balun footprint, LED polarity, CP2102N sensing/power circuit,
   and the D2 part/footprint mismatch; adopt functional IC symbols.
2. Reorient USB-C; resolve module antenna geometry; rebuild radio placement
   with local bypassing and short RF/oscillator paths.
3. Complete the exact BOM and thermal design, choose the fabrication stackup,
   and route power, ground, USB and RF with appropriate constraints.
4. Repeat netlist/pin audits, ERC, routed DRC and mechanical review before
   generating the five-board fabrication/assembly package.

Review only: schematic, PCB, generators and BOM were not changed by this review.

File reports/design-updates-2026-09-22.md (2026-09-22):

# Rev A1 correction record — 2026-09-22

Disposition: **review corrections implemented; still NOT FOR MANUFACTURE.**

The schematic, generated netlists, PCB, custom library, BOM inventory and renders
have been updated together. The previous review is retained unchanged as the
historical defect record. No Gerbers, purchase order or assembly release was made.

## Review findings and changes

| Finding | Implemented correction | Remaining qualification |
|---|---|---|
| CC1101 DGUARD grounded | U2.18 now +3V3_RF; dedicated C26 bypass | Power/ground routing and first-power measurements |
| Mirrored balun footprint | Top-view rows now 3–2–1 / 4–5–6; upper-right pin-1 mark | Physical part/tape orientation check before assembly |
| USB faces inward | J1 at (3.675,18) mm, −90°; recommended board-edge reference at x=0 | Connector-specific hole clearance and mechanical fit |
| CP2102N VBUS/power | 22.1k/47.5k sense divider; VIO/VDD/VREGIN on common external 3.3 V; 1k reset pull-up; local bypass pairs | Route and verify startup, USB enumeration and auto-reset |
| Reversed LEDs | D3/D4 pin 1 cathode to GND; pin 2 anode to resistor node | Assembly polarity and actual LED part selection |
| D2 package mismatch | PESD5V0S1UL now SOD-882, with explicit cathode/anode symbol | Confirm protection clamping and exact assembly package |
| Remote/missing decoupling | Repositioned C21–C25, crystal and bias resistor; added C26, C60/C61 and ESP32 C11/C12 | Short routed loops and ground stitching still required |
| ESP32 antenna over PCB | Module moved to y=6.30 mm; antenna tip y=−6.45 mm | Enclosure, nearby metal and RF testing |
| Small regulator thermal risk | AP7361C-33E-13 in SOT-223; grounded tab; preliminary heat spreading and eight vias | Load profile and measured thermal validation remain open |

Functional CC1101, BGS13SN8 and balun symbols replace generic connector symbols.
Pin types now provide more useful ERC, but ERC alone cannot identify every wrong
net assignment. The new `hardware/audit_design.py` checks generated artifacts for
the specific review regressions, rather than assuming the generator is correct.

Pin/source basis: [TI CC1101](https://www.ti.com/lit/ds/symlink/cc1101.pdf),
[Silicon Labs CP2102N](https://www.silabs.com/documents/public/data-sheets/cp2102n-datasheet.pdf),
[TTM balun](https://cdn.ttm.com/repository/products/wireless-xinger/balun-transformers/B0310J50100AHF/B0310J50100AHF.pdf),
[Nexperia D2](https://assets.nexperia.com/documents/data-sheet/PESD5V0S1UL.pdf).

## Placement and copper

- Base board remains 90 × 36 mm, four copper layers, nominal thickness 1.6 mm.
- Vertical SMA footprint remains at the end opposite USB-C. Exact SMA part
  approval is still pending. The installed matching 3D model is missing, so
  the renders show its lands, not the connector body. Custom RF package models
  are also absent; these renders are not a complete clearance certification.
- ESP32 overhang adds 6.45 mm to the base-board width before enclosure clearance.
  Its feed lies approximately 0.26 mm outside the board edge; keep the external
  antenna region clear of enclosure metal and wiring.
- U2 supply-pad to assigned bypass-pad distances are now 1.33–2.56 mm.
  Switch bypass distances are 1.68/1.26 mm. Crystal connections measure
  2.13/2.22 mm between pad centers. These are straight-line placement distances,
  **not** achieved routed lengths or evidence of RF performance.
- Initial In1.Cu/B.Cu GND zones and a front-side regulator heat-spreading zone
  are filled. Eight 0.60 mm diameter / 0.30 mm drill ground vias connect the
  regulator region. Final ground stitching, RF return paths, power routing,
  impedance geometry and layer-stackup definition are unfinished.

## Regulator screening — not a certified current limit

AP7361C-33E-13 uses IN/GND/OUT pins 1/2/3 and a grounded tab; the ER variant
has a different pinout. Its SOT-223 datasheet thermal figure is 110 °C/W on the
specified minimum-land test board. Our actual board resistance is unknown.
[Diodes AP7361C datasheet, pin descriptions and thermal information](https://www.diodes.com/datasheet/download/AP7361C.pdf).

Illustrative conservative screening assumes 5.25 V input, 3.267 V output
(−1%), and 40 °C ambient. Ignoring small quiescent losses:

| Continuous load | LDO dissipation | Estimated junction using 110 °C/W |
|---:|---:|---:|
| 300 mA | 0.595 W | 105 °C |
| 500 mA | 0.992 W | 149 °C |

These are calculations, not measurements. They show why even the larger
package does not justify claiming 500 mA continuous or 1 A board capacity.
Use 300 mA only as a provisional design-screening point, not an approved
operating rating. Validate Wi-Fi peaks, radio load, USB source capability,
fuse temperature derating, startup/inrush, capacitor effective capacitance and
worst-case ambient. A DC/DC redesign remains possible if measured load or
thermal margin requires it. No numerical thermal improvement is assumed from
the newly added copper without simulation or measurement.

## Fresh verification

- KiCad 10.0.6 schematic ERC: **0 violations**, `erc-corrected.json`.
- Targeted artifact audit: **107/107 pass**, `design-audit.json`.
- PCB DRC: **4 hole-clearance errors**, all internal to J1, 0.1944 mm actual
  versus configured 0.2500 mm minimum. No clearance rules were relaxed or
  violations excluded to obtain these results.
- **215 unconnected items**, zero routed signal/power tracks, eight standalone
  thermal vias and three board-level filled ground zones. Exposed-pad thermal
  holes embedded in footprints are additional and not counted as those vias.
- No reported pad shorts, ordinary copper-clearance violations, courtyard
  overlaps, edge-clearance violations or silkscreen collisions.
- BOM now covers all **103 schematic footprints**, including ordinary
  resistors/capacitors previously omitted. Four mounting-hole footprints are
  PCB-only mechanical features. DNPs/test pads are explicitly excluded from
  purchasing quantities; five-board counts do not include assembly attrition.
- Bring-up firmware: PlatformIO build succeeded (21,576 bytes RAM;
  274,913 bytes program usage reported). Firmware was not changed or flashed;
  this does not verify physical hardware or radio performance.
- Top/3D placement and schematic SVG exports refreshed and visually inspected.
  Schematic uses net labels; final routed review must trace complete net paths.

## Still required before five-board order

1. Select the fabricator's actual dielectric stackup and approved capabilities;
   resolve the connector clearance errors by supported geometry/rules or a
   verified connector change, then set controlled-impedance routing constraints.
2. Complete all power/signal/RF routing, decoupling ground loops and via fencing;
   rerun full DRC and independently review pin maps and RF topology.
3. Approve exact SMA, crystal, passive/RF series, fuse, ferrite, LEDs and other
   BOM options. The complete inventory is still **not** a procurement-ready BOM.
4. Complete the thermal/current design budget and protection review, and plan
   measured validation on the prototypes.
5. Review the unsupported low-band performance risk and arrange RF test access.
   The [BGS13SN8 datasheet](https://www.infineon.com/assets/row/public/documents/24/49/infineon-bgs13sn8-datasheet-en.pdf)
   does not supply the same tabulated RF guarantees at 315/433 MHz as at
   698 MHz and above. Matching values remain reference starting values.
6. Review fabrication/assembly outputs and physical connector orientation
   before authorizing the initial five assembled prototypes.

After prototypes exist, measure actual thermal/current behavior, characterize
315/433 MHz switch behavior and tune/test all RF branches before claiming
four-band performance. That validation is distinct from authorizing a
controlled prototype fabrication; it cannot be replaced by ERC or this audit.

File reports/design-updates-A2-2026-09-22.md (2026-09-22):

# A2 design updates — 2026-09-22

Disposition: **NOT ORDERABLE.** This pass fixes placement/part issues and adds
a separate, partially routed candidate. It does not complete the PCB or validate
four-band RF performance. No purchase, upload to a fabricator or TX test occurred.

## Implemented

- J1 changed from GCT USB4105 to HRO TYPE-C-31-M-12, with the matching KiCad
  footprint at (3.65, 18) mm, -90 degrees. The USB opening stays at the left
  edge; vertical standard SMA remains at the opposite end. Reviewed the base
  M-12 manufacturer drawing, not the alternate A/B/C variants. Original four
  hole-clearance errors are gone with the original 0.25 mm rule retained.
- D1 placement adjusted to clear the programming IC and connector escape area.
- Y1's old TXC 9HT11 footprint was inappropriate for the proposed 26 MHz
  crystal. Replaced it with exact Abracon ABM8-26.000MHZ-10-1-U-T and a custom
  four-pad footprint from the manufacturer's drawing. Updated symbol, ground
  pads, placement and BOM together. C31/C32 now 15 pF C0G, calculated from
  CL=10 pF and TI's typical 2.5 pF parasitics; actual trim remains unverified.
- Added POWER/RF_LOCAL/ANALOG_LOCAL/USB net classes and a 0.15 mm minimum trace
  width for fine-pitch escapes. No error exclusions or hole-clearance waivers.
- Added constrained local DSN export/import and routing audits. RF, analog and
  USB tracks remain top-only; In1.Cu is reserved for ground. Candidate carries
  its own copy of project rules so its native DRC is comparable.
- Proposed exact part numbers now cover 63 populated positions, including
  crystal, USB/SMA, fuse, bead, RF inductors and many resistors/bypass capacitors.
- Added a documented fabricator stackup target, power screening and bench/RF
  acceptance procedures in `docs/05-A2-routing-and-validation.md`.
- Refreshed top/3D placement images and schematic SVG. Missing connector/RF 3D
  bodies mean renders cannot establish connector clearance or antenna fit.

The PDF inspection workflow informed the USB and crystal land-pattern changes.
It did not constitute an independent engineering sign-off. Manufacturer sources
and calculations are linked in the validation document.

## Verification evidence

| Artifact/check | Result |
|---|---|
| `erc-A2.json` | 0 schematic ERC violations |
| `drc-A2-placement.json` | 0 violations; 217 unconnected items |
| `design-audit.json` | 115/115 checks pass; 107 footprints |
| Main placement board | 0 signal/power track segments; 8 thermal vias |
| `drc-A2-routing-candidate.json` | 0 violations; 23 unconnected items |
| `routing-audit-A2.json` | 735 track segments, 123 vias; 0 checked layer violations |
| Candidate power-width review | 35 segments below 0.40 mm target; unapproved |
| BOM | 103 footprint rows; 81 populated; 18 populated positions still unselected |

The two unconnected counts describe different files. The main board remains a
reproducible checked placement, while `hardware/A2-routing-candidate.kicad_pcb`
contains exploratory routing. It has not been promoted. Router completion,
router-specific DRC counts and native KiCad results are not interchangeable.
Use the native reports above; the local routing run stopped at its time limit.

Candidate unresolved connections include switch power/ground/control pads,
several RF paths, crystal Q2, CC1101 CSn, USB D+ and a ground-zone island.
Do not infer functional connectivity from the 0-violation clearance result.

## Remaining order blockers

1. Complete routing and manually review RF, crystal, USB, power and return paths.
   Calculate final impedance geometry against the confirmed manufacturing stackup.
   Remove inappropriate power neck-downs and any digital intrusion into RF/clock
   areas. Refill ground, resolve all airwires and repeat DRC/visual review.
2. Select C1, C2, C5, C10, C11, C20, C31, C32, C40, C41, C42, C44, C45, C47,
   C49, D3, D4 and R6. Verify DC-bias/tolerance, lifecycle, stock and assembly
   sourcing for every populated item. Existing proposed parts are not procurement
   approvals and five-unit quantities do not include spares.
3. Resolve supply capacity and USB current behavior. At the screening assumptions,
   a sustained 500 mA load gives approximately 149 C LDO junction temperature;
   there is inadequate margin. The actual PCB thermal performance is unmeasured.
4. Obtain an independent RF/layout review before ordering prototypes. The
   low-band switch performance and shared 868/915 matching need measurement on
   prototypes; budget for tuning/rework. No claim of equivalent performance to
   the Amazon module has been established.
5. Complete exact SMA drawing/physical-fit and assembly-orientation checks.

Before A2 edits, A1 hardware/docs/README were archived at
`reports/checkpoints/A1-hardware-before-routing.tar.gz`. Historical A1 reports
and images were retained. Current editable design sources are the generators;
regenerating placement overwrites manual routing, so preserve routing separately.

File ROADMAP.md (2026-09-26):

# Roadmap

An engineering plan, not a shipping schedule. An AI check or clean DRC alone
does not close a phase; all acceptance gates require human review.

## 1. Capture and document — substantially complete

- [x] ESP32-WROOM-32E-N8 + CC1101 architecture and GPIO map.
- [x] Software-selected three-path RF network for four target bands.
- [x] Schematic, placement, local footprints and draft BOM.
- [x] Safe-default bring-up firmware, renders and machine-readable checks.
- [x] Public documentation and AI disclosure prepared.

## 2. Pre-order engineering — in progress

- [x] Finish candidate connectivity: A3 native DRC has zero violations/unconnected items.
- [ ] Manually review RF, oscillator, USB pair, power and ground returns.
- [x] Replace the thermally constrained LDO with a buck and explicitly route main power.
- [ ] Approve branch-current/voltage-drop and buck load-step/thermal testing.
- [ ] Confirm USB current availability and startup behavior.
- [ ] Confirm fabricator stackup and 50-ohm RF / 90-ohm USB geometry.
- [x] Propose exact parts for all populated BOM positions.
- [ ] Verify current stock, authorized sourcing and assembler substitutions.
- [x] Relocate/reroute crystal to pass the original 3.5 mm placement screen;
  shorten the longest route and remove digital copper beneath the Q1 pad.
- [x] Add actual-path copper resistance and cross-layer oscillator screens.
- [ ] Independently review the refined clock layout; measure startup/frequency.
- [ ] Confirm filled/capped via processing at C21 and the USB bridge exposed pad.
- [ ] Review connectors, solder/paste, RF pin mapping and assembly orientation.
- [ ] Obtain independent electrical/RF review; repeat ERC/DRC/audits.

Exit: a routed, reviewed prototype order candidate with zero unexplained errors,
all connections complete, documented residual risks and a validation plan.
This is not the same as production-ready hardware.

## 3. Five engineering prototypes — not ordered

- [ ] Produce reviewed Gerbers, drills, BOM and pick-and-place outputs.
- [ ] Check supplier DFM feedback, placement preview and substitutions.
- [ ] Approve a quote/order separately; this roadmap does not authorize purchase.
- [ ] Receive, inspect, photograph and record revision IDs for five units.

## 4. Bench and RF qualification — not started

- [ ] Current-limited first power, rails, boot/reset and USB checks.
- [ ] SPI identity verification, thermal and transient-load measurements.
- [ ] Crystal startup/frequency accuracy over intended operating conditions.
- [ ] VNA measurements and tuning at 315, 433, 868 and 915 MHz.
- [ ] Characterize low-band switch loss/isolation and shared upper-band matching.
- [ ] Conducted sensitivity, output spectrum and harmonics with proper equipment.
- [ ] Record failures/rework; make Rev B if acceptance limits are not met.

Exit: measured results and an honest operating envelope, not assumed range
claims or equivalence to another module.

## 5. Firmware and usability — planned

- [x] Repeated ID validation, timeouts and 17 host fault-injection tests.
- [ ] Bench-validate diagnostics and develop repeatable factory tests.
- [ ] Receive-first frequency/modem profiles and a documented control interface.
- [ ] Verified IDLE/isolate/select/reconfigure sequence for band changes.
- [ ] Deliberately selected region/power profiles before transmit features.
- [ ] Evaluate optional Wi-Fi/Bluetooth control and logging, subject to testing.

## 6. Possible sale — undecided

- [ ] Choose markets, use cases and supported antenna combinations.
- [ ] Obtain commercial licensing/provenance review of third-party inputs.
- [ ] Determine applicable RF/EMC/safety requirements with qualified help.
- [ ] Resolve enclosure, labeling, test fixtures and production QA.
- [ ] Confirm sourcing, costs, support/warranty and manufacturing yield.
- [ ] Decide whether to sell and under what business/licensing model.

Publication does not constitute a sales, compliance or production decision.

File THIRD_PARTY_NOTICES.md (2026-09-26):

# Third-party notices and design provenance

LICENSE applies only to project material to the extent its rights are held by
the owner. It does not replace third-party terms, license trademarks/patents,
or establish ownership of technical facts.

## KiCad

Saved designs embed standard-library symbol/footprint data, and renders use
installed component models. KiCad libraries use CC BY-SA 4.0 with an exception
for electronic designs and generated files. The exception does not apply to
republishing libraries as a collection. Full standard libraries/models are not
vendored here. See the [official license and exception](https://www.kicad.org/libraries/license/).
Custom footprints and sources are described in [hardware/lib/README.md](hardware/lib/README.md).

## Reference circuitry and datasheets

- **Espressif:** module and development-board programming/reset conventions.
  [Module datasheet](https://documentation.espressif.com/esp32-wroom-32e_esp32-wroom-32ue_datasheet_en.html),
  [DevKitC documentation](https://docs.espressif.com/projects/esp-dev-kits/en/latest/esp32/esp32-devkitc/user_guide.html).
- **Texas Instruments:** CC1101 interfaces, oscillator and layout guidance.
  [CC1101 documentation](https://www.ti.com/product/CC1101).
- **M5Stack:** Cap CC1101 schematic, recorded basis Rev 0.3, informed the switched
  RF topology and starting filter/matching values.
  [Original reference](https://docs.m5stack.com/en/cap/Cap_CC1101).
  No claim is made that its separately hosted hardware PDF inherits a software
  repository license. Source PDF/images are not republished here. Confirm any
  applicable hardware reuse rights before commercial release.
- **Infineon (historical A1/A2), TTM/Anaren, Abracon:** drawings informed local RF/crystal footprints.
  [BGS13SN8](https://www.infineon.com/assets/row/public/documents/24/49/infineon-bgs13sn8-datasheet-en.pdf),
  [balun](https://cdn.ttm.com/repository/products/wireless-xinger/balun-transformers/B0310J50100AHF/B0310J50100AHF.pdf),
  [ABM8](https://abracon.com/Resonators/abm8.pdf).
- **pSemi and Diodes:** A3 switch/regulator pins and land patterns, from
  [PE42442](https://psemi.com/pdf/datasheets/pe42442ds.pdf) and
  [AP63203](https://www.diodes.com/assets/Datasheets/AP63200-AP63201-AP63203-AP63205.pdf).
- **Silicon Labs and TI:** A3 USB power sequencing, load switch and UART buffer,
  linked with exact component sources in the engineering notes.
- Other sources are linked in [A3 engineering notes](docs/06-A3-prototype-engineering.md)
  and design reports. Datasheets remain their publishers' material.

Circuit functions and component facts are distinguished from copyrighted
drawings/documentation. Public availability is not assumed to grant a blanket
right to relicense material. This inventory is not legal clearance or a
freedom-to-operate analysis.

## README image credits

| Image | Source and scope |
|---|---|
| `output/routing-A3-3d.png`, `output/routing-A3-top.svg`, `output/svg-A3/` | Current project KiCad renders/exports, 2026-09-26; unapproved prototype candidate |
| `output/placement-A2-3d.png`, `output/placement-A2-top.png` | Project KiCad renders, 2026-09-22; library/model terms above |
| `output/routing-A2-top.svg`, schematic SVG | Exports from project design files; experimental/draft status retained |
| ESP32-WROOM-32E reference | Externally hosted [Espressif image](https://www.espressif.com/sites/default/files/modules/ESP32-WROOM-32E%20S_0.png); owner's copyright, excluded from project license |
| CC1101 representative package | Externally hosted [TI RGP0020H image](https://www.ti.com/content/dam/ticom/images/products/package/r/rgp0020h.png); owner's copyright, excluded from project license |

Manufacturer images identify reference parts and link to their source pages.
They are not redistributed as locally licensed assets. External images may
change or fail to load. Names and marks belong to their owners; no endorsement
or sponsorship is implied.

## Software and tools

Firmware depends on Arduino/SPI and the ESP32 framework through PlatformIO.
Their licenses are not replaced by LICENSE. Build caches, dependencies and
binaries are excluded; review notices before distributing firmware binaries.

KiCad, kicad-sch-api, PlatformIO and Freerouting were development tools, not
reviewers/endorsers. Their executables and source distributions are not included
or relicensed here.

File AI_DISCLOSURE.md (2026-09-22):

# AI-assisted development disclosure

This project is directed by Bobby Dini and developed with substantial assistance
from OpenAI Codex. AI assisted with research, design-generation code, schematic
capture, local footprints, layout iterations, routing tools, bring-up firmware,
documentation and automated review.

The owner supplied goals and design preferences. That direction is not a
completed independent engineering review. An AI assistant or software check
is not a substitute for a qualified electrical/RF engineer, fabricator review,
physical measurements or compliance assessment.

## What the evidence means

- ERC/DRC reports describe configured checks at a recorded revision. They do
  not certify radio behavior, safety or manufacturability.
- Scripted checks cover selected properties, not every possible failure mode.
- KiCad renders/exports show saved design files, not working hardware, and
  may omit components with missing 3D models.
- Manufacturer reference images are attributed, not AI-created project assets.
- Partial routing is experimental and not approved for ordering.
- No physical unit or measured four-band result exists at the A2 checkpoint.

Before fabrication or sale, independently review pin mappings, footprints,
power/thermal budgets, USB/RF layout, source licenses and compliance. Record
measurements and failures, not just successful tool output. AI assistance does
not establish ownership of third-party material or assure copyrightability of
any particular output.

Issue reports with reproducible evidence and manufacturer references are welcome.
Disclose substantial AI assistance in proposed changes. Do not submit third-party
material without appropriate permission. Contribution licensing must be agreed
before substantive outside contributions are merged; no rights assignment or
contributor license agreement is implied.

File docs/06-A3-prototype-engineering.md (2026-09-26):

# A3 prototype engineering decisions

Updated 2026-09-26. This is an engineering prototype, not a proven four-band
product. No board has been assembled or measured. Do not order historical A2
files, mix A2 firmware with A3, or treat a clean DRC as RF qualification.

## Power and USB startup

U6 is now **AP63203WU-7**, a fixed 3.3 V switching regulator, with a 4.7 uH
Coilcraft XAL4030-472MEC and two 22 uF output capacitors. The linear regulator's
approximately 0.94 W dissipation at 550 mA/5 V becomes about 0.32 W converter
loss **if** efficiency is 85%. This is a screening calculation, not a measured
thermal rating. The IC's 2 A rating is not the board or USB power allowance.
[Diodes datasheet](https://www.diodes.com/assets/Datasheets/AP63200-AP63201-AP63203-AP63205.pdf).

C1/C2/C13 use 25 V, 1206 parts after inspecting Yageo's DC-bias curves. The
original proposed 10 V/0805 parts lost too much effective capacitance. See the
[exact 1206 part](https://www.yageogroup.com/component-documentation/download/specsheet/CC1206MKX5R8BB226).
Typical curves are not minimum guaranteed capacitance; aging and load-step
behavior still need review and measurement.

F1 is MF-NSMF075/13X-2: the old MF-NSMF050 is marked NRND and its hold current
falls to 0.40 A at 50 C. The replacement has 0.61 A hold at 50 C and 0.35 ohm
maximum post-reflow resistance at 23 C. **A PTC is not a 500 mA current limiter.**
[Bourns datasheet](https://www.bourns.com/docs/product-datasheets/mf-nsmf.pdf).

The CP2102N runs from protected VBUS and supplies its own VDD/VIO rail,
`+3V3_USB`. Its SUSPENDb signal controls TPS22918, which ramps power to the
main regulator only after USB configuration. A 10 nF/50 V CT capacitor gives
approximately 27.65 ms typical 10–90% rise at 5 V. The load switch is not
overcurrent protection or a USB-PD controller.
[CP2102N datasheet](https://www.silabs.com/documents/public/data-sheets/cp2102n-datasheet.pdf),
[TPS22918 datasheet](https://www.ti.com/lit/ds/symlink/tps22918.pdf).

U8 SN74LVC2G125DCTR buffers both UART directions on the main rail. Its Ioff
feature addresses back-powering through UART while the ESP32 is off. Auto-reset
transistor behavior, leakage and power sequencing still need bench checks.
[TI buffer datasheet](https://www.ti.com/lit/ds/symlink/sn74lvc2g125.pdf).

### J4: one-time power setup, not an RF switch

Ship the shunt **loose/unfitted**. First connect USB with only the CP2102N powered.
Using Silicon Labs' configuration utility, configure and read back the USB
descriptor for **bus-powered 500 mA**, retain the intended SUSPENDb behavior,
then unplug and fit J4 pins **1–2 (AUTO)**. Verify the host grants configuration
before the ESP32 rail rises. Suspend will turn the main rail off.

Pins **2–3 (EXT)** force power on and are only for a separately verified,
adequately rated regulated **5 V** source. They do not negotiate extra USB
current. Never use 9/12/20 V PD-trigger cables. U7 is a low-voltage part even
though the buck alone accepts higher voltages. Never connect external power
to J3 while USB is attached; there is no source-ORing circuit.

Initial testing is indoor, with Wi-Fi off, diagnostic-only firmware and a
current-limited supply. The full ESP32/radio load may exceed a 500 mA USB
budget at low cable-end voltage. Do not promise arbitrary-port operation or
unrestricted simultaneous Wi-Fi/radio transmission. Validate before adding
those modes. [Reproducible calculations](../reports/engineering-budget-A3.json).

## RF switches and software mapping

U3/U4 are **PE42442A-Z SP4T** switches specified for 30 MHz–6 GHz. Three ports
carry the filters; the fourth is externally terminated with 49.9 ohm. The
selection fixes the previous switch's low-band specification gap, but not the
matching network's unmeasured performance. Expect roughly two switch losses
in series; do not quote the IC's insertion loss as whole-board loss.
[pSemi datasheet](https://psemi.com/pdf/datasheets/pe42442ds.pdf).

The output switch's outer branches are reversed for planar routing, so it has
independent controls. The table is written **V1, V2**, not binary-number order.

| Mode | RF_DISABLE / V3 | U3 V1,V2 / GPIO32,33 | U4 V1,V2 / GPIO16,17 |
|---|---:|---|---|
| Safe boot | 1 | 1,1 | 1,1 |
| 315 MHz | 0 | 1,0 | 1,1 |
| 433 MHz | 0 | 0,1 | 0,1 |
| 868 or 915 MHz | 0 | 1,1 | 1,0 |

GPIO4 drives V3 on both switches. Five external **10 kohm pullups** establish
111 before firmware. They are stronger than the initially considered 100 kohm
parts, allowing more margin against internal pulls/leakage. Verify startup on
a scope. **000 selects RF4; it is not the all-off state.** GPIO16/17 on J3 are
now RF debug taps, not spare GPIOs. A3 diagnostics never select an active path.

Future selection must require stable CC1101 IDLE, drive V3 high, wait, update
both selectors, wait, lower V3, then configure/calibrate the radio. Respect the
switch's 25 kHz normal-mode maximum switching rate; use at least 50 us between
selection events. No RX/TX command interface is implemented yet.

## Routing, stackup and matching

The proposed stackup is JLC04161H-7628: 0.2104 mm top dielectric, Dk 4.4,
35 um outer copper. L2/In1 is the unbroken ground reference, with no signal
traces. Long RF runs use a **0.35 mm starting width**, short QFN necks are
0.20 mm. The main USB paired section uses 0.30 mm width / 0.20 mm gap; the
connector crossover and uncoupled transitions differ.
[Fabricator stackup](https://jlcpcb.com/impedance).

These geometries are first-order proposals, not impedance certificates. Get
fabricator confirmation including solder mask, etched trace shape and nearby
copper. Inspect return paths and the USB connector crossover. No blind/microvias
are used; small escape vias are 0.50/0.20 mm pad/drill, ordinary vias 0.60/0.30.

Native candidate DRC is **0 violations / 0 unconnected items** and fresh
schematic-to-PCB pin/value/footprint-name parity passes. The placement seed
is intentionally unrouted. C60 is shifted 0.4 mm north in the finishing step.
Two via centers lie inside SMD pads: C21.1 at (46.5,18.9) and U5 exposed
ground pad at (16,19.4), in mm. Require **resin fill and copper capping** at
these positions and supplier review of every pad-adjacent via. These are not
permission to use open via-in-pad or to assume ordinary low-cost processing.
The stackup's loss tangent 0.02 and solder-mask thickness 0.01 mm are modeling
assumptions, not verified supplier values; they are not impedance certification.

Power switching, RF and crystal routes are generated explicitly before the
remaining digital routing. RF ground lands connect to the switch exposed
paddles and nearby ground vias. R40's redundant zero-ohm series jumper was
removed to eliminate a detour; L41 now feeds the input switch directly.

The crystal now uses a -37.5 degree diagonal orientation with relocated load
capacitors and rerouted digital/power escapes. Both pin-center distances
(3.468 / 3.479 mm) meet the unchanged 3.5 mm screening goal. Actual clock
routes are 4.299 / 3.994 mm, without vias. Digital copper on every layer is
outside the projected Q1 pad by at least 0.2079 mm, against a new 0.20 mm
project screen. These numerical screens are not manufacturer qualification.
Record load trim, cold-start behavior, frequency and probe loading during
review; do not casually probe the oscillator with a high-capacitance probe.
[CC1101 oscillator/layout guidance](https://www.ti.com/lit/ds/symlink/cc1101.pdf).

The new [routed-path model](../reports/route-margins-A3.json) estimates 7.423 mV
drop in the main ESP32 copper path at 0.5 A, with 0.8 mm minimum trace width.
It assumes 80 C copper, 80% of target copper thickness and 20 um via plating.
It omits components, pad spreading, cable and ground-return resistance, and
does not model temperature rise, transients or RF noise. Its independent load
cases are not an approved simultaneous-load budget. The remaining 60 narrow
branch/neck segments remain listed; a narrow trace is not automatically an
error when its current is small, nor does this model approve every branch.

The balun and filter values remain reference-derived starting values, not a
four-band match. Board parasitics and the new switch packages alter the circuit.
VNA tuning, conducted RX tests and spectral tests are necessary. A single SMA
does not make an antenna broadband. No guaranteed range or sensitivity is claimed.

## Five-board acceptance plan

1. Independent schematic/layout review and supplier DFM/impedance confirmation
   on the exact file hashes; approve stock, footprints, paste and substitutions.
2. Assemble five only after a separately authorized quote. Inspect the first
   board for shorts and polarity before powering all five.
3. Configure/read back CP2102N with J4 open. Check USB enumeration, then AUTO
   power-up, suspend/resume, UART flashing and manual/automatic BOOT/RESET.
4. Measure 3.3 V during startup and 0–500 mA load steps; check input current,
   fuse drop, regulator/inductor temperature and RF rail noise. Reject rail
   dips below the ESP32 module's 3.0 V minimum.
5. Run diagnostics repeatedly on all five. Confirm crystal startup and actual
   frequency. A passing ID read is not an RF test.
6. Tune and measure each RF path into 50 ohm equipment, using a suitable
   attenuator and authorized test conditions. Record per-band insertion loss,
   return loss, receive performance and any rework. Transmit remains disabled
   until spectral and applicable operating-limit checks are complete.

An RF engineer can review/tune the exact prototype remotely or in a lab; these
measurements cannot be supplied by code alone. Keep at least one board in its
original population as a comparison while tuning another.

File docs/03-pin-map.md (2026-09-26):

# A3 ESP32 pin map

| GPIO | Function |
|---:|---|
| 0 | BOOT / automatic programming; strapping pin |
| 1 / 3 | UART TX / RX through powered-off-protected buffer |
| 4 | RF_DISABLE, V3 of both switches; HIGH disables |
| 16 / 17 | RF_OUT0 / RF_OUT1, U4 V1 / V2 |
| 18 / 19 / 23 | CC1101 SCLK / MISO / MOSI |
| 21 | CC1101 CSn |
| 25 | Active-high status LED |
| 26 / 27 | CC1101 GDO0 / GDO2 |
| 32 / 33 | RF_SW0 / RF_SW1, U3 V1 / V2 |

GPIO16/17 exposed at optional J3 are RF debug taps, **not spare outputs**.
GPIO13/14/22 and input-only GPIO34/35 are expansion candidates; do not
drive the radio-control taps externally. GPIO6–11 belong to internal flash.
GPIO2/5/12/15 remain unused strapping pins; GPIO4 is not a strapping pin.

## Switch states

| Mode | GPIO4 | GPIO32,33 | GPIO16,17 |
|---|---:|---|---|
| Isolated boot | 1 | 1,1 | 1,1 |
| 315 MHz | 0 | 1,0 | 1,1 |
| 433 MHz | 0 | 0,1 | 0,1 |
| 868/915 MHz | 0 | 1,1 | 1,0 |

Five 10 kohm pullups establish HIGH before firmware. The startup helper
preloads all outputs HIGH before enabling their drivers. **000 selects RF4;
it does not isolate.** Never use A2's old switch helper on this board.

Future selection: require stable CC1101 IDLE, raise GPIO4, wait at least
50 us, set both independent selector pairs, wait at least 50 us, lower
GPIO4, configure/calibrate the radio and verify completion. Respect the
switch's maximum switching rate. Receive/transmit and this selection sequence
are not implemented in the current diagnostic-only firmware.

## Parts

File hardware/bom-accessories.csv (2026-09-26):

Item | Proposed part | Qty per board | Qty for five | Notes
J4 loose shunt | SNT-100-BK-G | 1 | 5 | Do not fit before CP2102N configuration. Verify stock; no order authorized.

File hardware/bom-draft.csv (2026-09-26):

Reference | Value | Footprint | Proposed part | DNP | Qty per board | Qty for five | Status | Notes
B1 | B0310J50100AHF | ESP32_CC1101_RF:TTM_B0310J50100AHF | B0310J50100AHF | no | 1 | 5 | VERIFY_STOCK_AND_ASSEMBLY
C1 | 22uF 25V | Capacitor_SMD:C_1206_3216Metric | CC1206MKX5R8BB226 | no | 1 | 5 | VERIFY_STOCK_AND_ASSEMBLY | 22uF 25V X5R 1206; bias curve reviewed. Verify effective capacitance, aging and transient margin on hardware.
C2 | 22uF 25V | Capacitor_SMD:C_1206_3216Metric | CC1206MKX5R8BB226 | no | 1 | 5 | VERIFY_STOCK_AND_ASSEMBLY | 22uF 25V X5R 1206; bias curve reviewed. Verify effective capacitance, aging and transient margin on hardware.
C3 | 4.7uF | Capacitor_SMD:C_0603_1608Metric | GRM188R61A475KE15D | no | 1 | 5 | VERIFY_STOCK_AND_ASSEMBLY | Verify selected tolerance, voltage/current rating and applicable DC-bias derating.
C4 | 100nF | Capacitor_SMD:C_0402_1005Metric | GRM155R71C104KA88D | no | 1 | 5 | VERIFY_STOCK_AND_ASSEMBLY | Verify selected tolerance, voltage/current rating and applicable DC-bias derating.
C5 | 4.7nF 1kV | Capacitor_SMD:C_1206_3216Metric | CC1206KKX7RCBB472 | no | 1 | 5 | VERIFY_STOCK_AND_ASSEMBLY | Verify selected tolerance, voltage/current rating and applicable DC-bias derating.
C6 | 100nF | Capacitor_SMD:C_0402_1005Metric | GRM155R71C104KA88D | no | 1 | 5 | VERIFY_STOCK_AND_ASSEMBLY | Verify selected tolerance, voltage/current rating and applicable DC-bias derating.
C7 | 100nF | Capacitor_SMD:C_0402_1005Metric | GRM155R71C104KA88D | no | 1 | 5 | VERIFY_STOCK_AND_ASSEMBLY | Verify selected tolerance, voltage/current rating and applicable DC-bias derating.
C8 | DNP | Capacitor_SMD:C_0603_1608Metric | GRM188R61A475KE15D | yes | 0 | 0 | DNP_DEFAULT | Verify selected tolerance, voltage/current rating and applicable DC-bias derating.
C9 | 4.7uF | Capacitor_SMD:C_0603_1608Metric | GRM188R61A475KE15D | no | 1 | 5 | VERIFY_STOCK_AND_ASSEMBLY | Verify selected tolerance, voltage/current rating and applicable DC-bias derating.
C10 | 1uF | Capacitor_SMD:C_0603_1608Metric | CC0603KRX7R7BB105 | no | 1 | 5 | VERIFY_STOCK_AND_ASSEMBLY | Verify selected tolerance, voltage/current rating and applicable DC-bias derating.
C11 | 10uF | Capacitor_SMD:C_0603_1608Metric | CC0603KRX5R6BB106 | no | 1 | 5 | VERIFY_STOCK_AND_ASSEMBLY | Verify selected tolerance, voltage/current rating and applicable DC-bias derating.
C12 | 100nF | Capacitor_SMD:C_0402_1005Metric | GRM155R71C104KA88D | no | 1 | 5 | VERIFY_STOCK_AND_ASSEMBLY | Verify selected tolerance, voltage/current rating and applicable DC-bias derating.
C13 | 22uF 25V | Capacitor_SMD:C_1206_3216Metric | CC1206MKX5R8BB226 | no | 1 | 5 | VERIFY_STOCK_AND_ASSEMBLY | 22uF 25V X5R 1206; bias curve reviewed. Verify effective capacitance, aging and transient margin on hardware.
C14 | 100nF | Capacitor_SMD:C_0402_1005Metric | GRM155R71C104KA88D | no | 1 | 5 | VERIFY_STOCK_AND_ASSEMBLY | Verify selected tolerance, voltage/current rating and applicable DC-bias derating.
C20 | 10uF | Capacitor_SMD:C_0603_1608Metric | CC0603KRX5R6BB106 | no | 1 | 5 | VERIFY_STOCK_AND_ASSEMBLY | Verify selected tolerance, voltage/current rating and applicable DC-bias derating.
C21 | 100nF | Capacitor_SMD:C_0402_1005Metric | GRM155R71C104KA88D | no | 1 | 5 | VERIFY_STOCK_AND_ASSEMBLY | Verify selected tolerance, voltage/current rating and applicable DC-bias derating.
C22 | 100nF | Capacitor_SMD:C_0402_1005Metric | GRM155R71C104KA88D | no | 1 | 5 | VERIFY_STOCK_AND_ASSEMBLY | Verify selected tolerance, voltage/current rating and applicable DC-bias derating.
C23 | 100nF | Capacitor_SMD:C_0402_1005Metric | GRM155R71C104KA88D | no | 1 | 5 | VERIFY_STOCK_AND_ASSEMBLY | Verify selected tolerance, voltage/current rating and applicable DC-bias derating.
C24 | 100nF | Capacitor_SMD:C_0402_1005Metric | GRM155R71C104KA88D | no | 1 | 5 | VERIFY_STOCK_AND_ASSEMBLY | Verify selected tolerance, voltage/current rating and applicable DC-bias derating.
C25 | 100nF | Capacitor_SMD:C_0402_1005Metric | GRM155R71C104KA88D | no | 1 | 5 | VERIFY_STOCK_AND_ASSEMBLY | Verify selected tolerance, voltage/current rating and applicable DC-bias derating.
C26 | 100nF | Capacitor_SMD:C_0402_1005Metric | GRM155R71C104KA88D | no | 1 | 5 | VERIFY_STOCK_AND_ASSEMBLY | Verify selected tolerance, voltage/current rating and applicable DC-bias derating.
C30 | 100nF | Capacitor_SMD:C_0402_1005Metric | GRM155R71C104KA88D | no | 1 | 5 | VERIFY_STOCK_AND_ASSEMBLY | Verify selected tolerance, voltage/current rating and applicable DC-bias derating.
C31 | 15pF C0G | Capacitor_SMD:C_0402_1005Metric | CC0402JRNPO9BN150 | no | 1 | 5 | VERIFY_STOCK_AND_ASSEMBLY | 15 pF C0G starting value uses TI typical 2.5 pF total stray: 15/2+2.5=10 pF. Measure/trim.
C32 | 15pF C0G | Capacitor_SMD:C_0402_1005Metric | CC0402JRNPO9BN150 | no | 1 | 5 | VERIFY_STOCK_AND_ASSEMBLY | 15 pF C0G starting value uses TI typical 2.5 pF total stray: 15/2+2.5=10 pF. Measure/trim.
C40 | 100pF C0G | Capacitor_SMD:C_0402_1005Metric | CC0402JRNPO9BN101 | no | 1 | 5 | VERIFY_STOCK_AND_ASSEMBLY | RF starting value; choose RF-rated series/Q/SRF and tune on actual PCB.
C41 | 100pF C0G | Capacitor_SMD:C_0402_1005Metric | CC0402JRNPO9BN101 | no | 1 | 5 | VERIFY_STOCK_AND_ASSEMBLY | RF starting value; choose RF-rated series/Q/SRF and tune on actual PCB.
C42 | 0.6pF C0G | Capacitor_SMD:C_0402_1005Metric | CC0402BRNPO9BNR60 | no | 1 | 5 | VERIFY_STOCK_AND_ASSEMBLY | RF starting value; choose RF-rated series/Q/SRF and tune on actual PCB.
C43 | DNP | Capacitor_SMD:C_0402_1005Metric |  | yes | 0 | 0 | DNP_DEFAULT | RF starting value; choose RF-rated series/Q/SRF and tune on actual PCB.
C44 | 1.2pF C0G | Capacitor_SMD:C_0402_1005Metric | CC0402BRNPO9BN1R2 | no | 1 | 5 | VERIFY_STOCK_AND_ASSEMBLY | RF starting value; choose RF-rated series/Q/SRF and tune on actual PCB.
C45 | 8pF C0G | Capacitor_SMD:C_0402_1005Metric | CC0402CRNPO9BN8R0 | no | 1 | 5 | VERIFY_STOCK_AND_ASSEMBLY | RF starting value; choose RF-rated series/Q/SRF and tune on actual PCB.
C46 | DNP | Capacitor_SMD:C_0402_1005Metric |  | yes | 0 | 0 | DNP_DEFAULT | RF starting value; choose RF-rated series/Q/SRF and tune on actual PCB.
C47 | 10pF C0G | Capacitor_SMD:C_0402_1005Metric | CC0402JRNPO9BN100 | no | 1 | 5 | VERIFY_STOCK_AND_ASSEMBLY | RF starting value; choose RF-rated series/Q/SRF and tune on actual PCB.
C48 | DNP | Capacitor_SMD:C_0402_1005Metric |  | yes | 0 | 0 | DNP_DEFAULT | RF starting value; choose RF-rated series/Q/SRF and tune on actual PCB.
C49 | 6.2pF C0G | Capacitor_SMD:C_0402_1005Metric | CC0402CRNPO9BN6R2 | no | 1 | 5 | VERIFY_STOCK_AND_ASSEMBLY | RF starting value; choose RF-rated series/Q/SRF and tune on actual PCB.
C50 | DNP | Capacitor_SMD:C_0402_1005Metric |  | yes | 0 | 0 | DNP_DEFAULT | RF starting value; choose RF-rated series/Q/SRF and tune on actual PCB.
C51 | DNP | Capacitor_SMD:C_0402_1005Metric |  | yes | 0 | 0 | DNP_DEFAULT | RF starting value; choose RF-rated series/Q/SRF and tune on actual PCB.
C52 | DNP | Capacitor_SMD:C_0402_1005Metric |  | yes | 0 | 0 | DNP_DEFAULT | RF starting value; choose RF-rated series/Q/SRF and tune on actual PCB.
C53 | DNP | Capacitor_SMD:C_0402_1005Metric |  | yes | 0 | 0 | DNP_DEFAULT | RF starting value; choose RF-rated series/Q/SRF and tune on actual PCB.
C54 | DNP | Capacitor_SMD:C_0402_1005Metric |  | yes | 0 | 0 | DNP_DEFAULT | RF starting value; choose RF-rated series/Q/SRF and tune on actual PCB.
C60 | 100nF | Capacitor_SMD:C_0402_1005Metric | GRM155R71C104KA88D | no | 1 | 5 | VERIFY_STOCK_AND_ASSEMBLY | Verify selected tolerance, voltage/current rating and applicable DC-bias derating.
C61 | 100nF | Capacitor_SMD:C_0402_1005Metric | GRM155R71C104KA88D | no | 1 | 5 | VERIFY_STOCK_AND_ASSEMBLY | Verify selected tolerance, voltage/current rating and applicable DC-bias derating.
C70 | 10nF | Capacitor_SMD:C_0402_1005Metric | CC0402KRX7R9BB103 | no | 1 | 5 | VERIFY_STOCK_AND_ASSEMBLY | Verify selected tolerance, voltage/current rating and applicable DC-bias derating.
C71 | 100nF | Capacitor_SMD:C_0402_1005Metric | GRM155R71C104KA88D | no | 1 | 5 | VERIFY_STOCK_AND_ASSEMBLY | Verify selected tolerance, voltage/current rating and applicable DC-bias derating.
D1 | USBLC6-2SC6 | Package_TO_SOT_SMD:SOT-23-6 | USBLC6-2SC6 | no | 1 | 5 | VERIFY_STOCK_AND_ASSEMBLY
D2 | PESD5V0S1UL | Diode_SMD:D_SOD-882 | PESD5V0S1UL | no | 1 | 5 | VERIFY_STOCK_AND_ASSEMBLY
D3 | STATUS GREEN | LED_SMD:LED_0603_1608Metric | APT1608LZGCK | no | 1 | 5 | VERIFY_STOCK_AND_ASSEMBLY
D4 | POWER GREEN | LED_SMD:LED_0603_1608Metric | APT1608LZGCK | no | 1 | 5 | VERIFY_STOCK_AND_ASSEMBLY
D5 | RF ESD DNP | Diode_SMD:D_0402_1005Metric |  | yes | 0 | 0 | DNP_DEFAULT
F1 | 750mA PTC | Fuse:Fuse_1206_3216Metric | MF-NSMF075/13X-2 | no | 1 | 5 | VERIFY_STOCK_AND_ASSEMBLY | Bourns 1206, hold 0.75 A at 23 C / 0.61 A at 50 C, 13.2 V, R1max 0.35ohm. NOT a USB current limiter; test fault/thermal behavior.
FB1 | 600R@100MHz | Inductor_SMD:L_0603_1608Metric | BLM18AG601SN1D | no | 1 | 5 | VERIFY_STOCK_AND_ASSEMBLY | Murata 0603, 600 ohm at 100 MHz, 0.5 A, DCR <=0.38 ohm.
J1 | USB-C USB2.0 | Connector_USB:USB_C_Receptacle_HRO_TYPE-C-31-M-12 | TYPE-C-31-M-12 | no | 1 | 5 | VERIFY_STOCK_AND_ASSEMBLY | HRO base M-12 variant; do not substitute M-12A/B/C without drawing review.
J2 | SMA FEMALE VERTICAL 50 OHM | Connector_Coaxial:SMA_Amphenol_132134_Vertical | 132134 | no | 1 | 5 | VERIFY_STOCK_AND_ASSEMBLY | Amphenol standard SMA female straight TH, 50 ohm; drawing/physical fit approval pending.
J3 | EXPANSION (DNP) | Connector_PinHeader_2.54mm:PinHeader_1x10_P2.54mm_Vertical |  | yes | 0 | 0 | DNP_DEFAULT
J4 | POWER ARM AUTO / EXT | Connector_PinHeader_2.54mm:PinHeader_1x03_P2.54mm_Vertical | TSW-103-07-G-S | no | 1 | 5 | VERIFY_STOCK_AND_ASSEMBLY | Ship UNJUMPERED; loose SNT-100-BK-G accessory. AUTO 1-2 only after CP2102N 500mA configuration; EXT 2-3 only adequate 5V source.
L1 | 4.7uH XAL4030 | Inductor_SMD:L_Coilcraft_XAL4030-XXX | XAL4030-472MEC | no | 1 | 5 | VERIFY_STOCK_AND_ASSEMBLY | 4.7uH +/-20%; 44.1mOhm max DCR; marked terminal 1 toward BUCK_SW. Verify temperature/ripple.
L40 | 3.3nH 5% | Inductor_SMD:L_0402_1005Metric | 0402HP-3N3XJRW | no | 1 | 5 | VERIFY_STOCK_AND_ASSEMBLY | RF starting value; choose RF-rated series/Q/SRF and tune on actual PCB.
L41 | 6.8nH 5% | Inductor_SMD:L_0402_1005Metric | 0402HP-6N8XJRW | no | 1 | 5 | VERIFY_STOCK_AND_ASSEMBLY | RF starting value; choose RF-rated series/Q/SRF and tune on actual PCB.
L42 | 10nH 5% | Inductor_SMD:L_0402_1005Metric | 0402HP-10NXJRW | no | 1 | 5 | VERIFY_STOCK_AND_ASSEMBLY | RF starting value; choose RF-rated series/Q/SRF and tune on actual PCB.
L43 | 0R | Inductor_SMD:L_0402_1005Metric | RC0402JR-070RL | no | 1 | 5 | VERIFY_STOCK_AND_ASSEMBLY | RF starting value; choose RF-rated series/Q/SRF and tune on actual PCB.
L44 | 10nH 5% | Inductor_SMD:L_0402_1005Metric | 0402HP-10NXJRW | no | 1 | 5 | VERIFY_STOCK_AND_ASSEMBLY | RF starting value; choose RF-rated series/Q/SRF and tune on actual PCB.
L45 | 3.6nH 5% | Inductor_SMD:L_0402_1005Metric | 0402HP-3N6XJRW | no | 1 | 5 | VERIFY_STOCK_AND_ASSEMBLY | RF starting value; choose RF-rated series/Q/SRF and tune on actual PCB.
L46 | 0R | Inductor_SMD:L_0402_1005Metric | RC0402JR-070RL | no | 1 | 5 | VERIFY_STOCK_AND_ASSEMBLY | RF starting value; choose RF-rated series/Q/SRF and tune on actual PCB.
L47 | 0R | Inductor_SMD:L_0402_1005Metric | RC0402JR-070RL | no | 1 | 5 | VERIFY_STOCK_AND_ASSEMBLY | RF starting value; choose RF-rated series/Q/SRF and tune on actual PCB.
L48 | 15nH 5% | Inductor_SMD:L_0402_1005Metric | 0402HP-15NXJRW | no | 1 | 5 | VERIFY_STOCK_AND_ASSEMBLY | RF starting value; choose RF-rated series/Q/SRF and tune on actual PCB.
L49 | 0R | Inductor_SMD:L_0402_1005Metric | RC0402JR-070RL | no | 1 | 5 | VERIFY_STOCK_AND_ASSEMBLY | RF starting value; choose RF-rated series/Q/SRF and tune on actual PCB.
L50 | 0R | Inductor_SMD:L_0402_1005Metric | RC0402JR-070RL | no | 1 | 5 | VERIFY_STOCK_AND_ASSEMBLY | RF starting value; choose RF-rated series/Q/SRF and tune on actual PCB.
L51 | 10nH 5% | Inductor_SMD:L_0402_1005Metric | 0402HP-10NXJRW | no | 1 | 5 | VERIFY_STOCK_AND_ASSEMBLY | RF starting value; choose RF-rated series/Q/SRF and tune on actual PCB.
L52 | 2.2nH 5% | Inductor_SMD:L_0402_1005Metric | 0402HP-2N2XJRW | no | 1 | 5 | VERIFY_STOCK_AND_ASSEMBLY | RF starting value; choose RF-rated series/Q/SRF and tune on actual PCB.
Q1 | MMBT3904 | Package_TO_SOT_SMD:SOT-23 | MMBT3904 | no | 1 | 5 | VERIFY_STOCK_AND_ASSEMBLY
Q2 | MMBT3904 | Package_TO_SOT_SMD:SOT-23 | MMBT3904 | no | 1 | 5 | VERIFY_STOCK_AND_ASSEMBLY
R1 | 5.1k 1% | Resistor_SMD:R_0603_1608Metric | RC0603FR-075K1L | no | 1 | 5 | VERIFY_STOCK_AND_ASSEMBLY | Verify selected tolerance, voltage/current rating and applicable DC-bias derating.
R2 | 5.1k 1% | Resistor_SMD:R_0603_1608Metric | RC0603FR-075K1L | no | 1 | 5 | VERIFY_STOCK_AND_ASSEMBLY | Verify selected tolerance, voltage/current rating and applicable DC-bias derating.
R3 | 1k | Resistor_SMD:R_0603_1608Metric | RC0603FR-071KL | no | 1 | 5 | VERIFY_STOCK_AND_ASSEMBLY | Verify selected tolerance, voltage/current rating and applicable DC-bias derating.
R4 | 1M | Resistor_SMD:R_0603_1608Metric | RC0603FR-071ML | no | 1 | 5 | VERIFY_STOCK_AND_ASSEMBLY | Verify selected tolerance, voltage/current rating and applicable DC-bias derating.
R5 | 22.1k 1% | Resistor_SMD:R_0603_1608Metric | RC0603FR-0722K1L | no | 1 | 5 | VERIFY_STOCK_AND_ASSEMBLY | Verify selected tolerance, voltage/current rating and applicable DC-bias derating.
R6 | 47.5k 1% | Resistor_SMD:R_0603_1608Metric | RC0603FR-0747K5L | no | 1 | 5 | VERIFY_STOCK_AND_ASSEMBLY | Verify selected tolerance, voltage/current rating and applicable DC-bias derating.
R10 | 10k | Resistor_SMD:R_0603_1608Metric | RC0603FR-0710KL | no | 1 | 5 | VERIFY_STOCK_AND_ASSEMBLY | Verify selected tolerance, voltage/current rating and applicable DC-bias derating.
R11 | 10k | Resistor_SMD:R_0603_1608Metric | RC0603FR-0710KL | no | 1 | 5 | VERIFY_STOCK_AND_ASSEMBLY | Verify selected tolerance, voltage/current rating and applicable DC-bias derating.
R12 | 330R 1% | Resistor_SMD:R_0603_1608Metric | RC0603FR-07330RL | no | 1 | 5 | VERIFY_STOCK_AND_ASSEMBLY | Verify selected tolerance, voltage/current rating and applicable DC-bias derating.
R13 | 330R 1% | Resistor_SMD:R_0603_1608Metric | RC0603FR-07330RL | no | 1 | 5 | VERIFY_STOCK_AND_ASSEMBLY | Verify selected tolerance, voltage/current rating and applicable DC-bias derating.
R20 | 10k | Resistor_SMD:R_0603_1608Metric | RC0603FR-0710KL | no | 1 | 5 | VERIFY_STOCK_AND_ASSEMBLY | Verify selected tolerance, voltage/current rating and applicable DC-bias derating.
R21 | 10k | Resistor_SMD:R_0603_1608Metric | RC0603FR-0710KL | no | 1 | 5 | VERIFY_STOCK_AND_ASSEMBLY | Verify selected tolerance, voltage/current rating and applicable DC-bias derating.
R30 | 56k 1% | Resistor_SMD:R_0402_1005Metric | RC0402FR-0756KL | no | 1 | 5 | VERIFY_STOCK_AND_ASSEMBLY | Verify selected tolerance, voltage/current rating and applicable DC-bias derating.
R31 | 10k pullup | Resistor_SMD:R_0603_1608Metric | RC0603FR-0710KL | no | 1 | 5 | VERIFY_STOCK_AND_ASSEMBLY | Verify selected tolerance, voltage/current rating and applicable DC-bias derating.
R32 | 10k pullup | Resistor_SMD:R_0603_1608Metric | RC0603FR-0710KL | no | 1 | 5 | VERIFY_STOCK_AND_ASSEMBLY | Verify selected tolerance, voltage/current rating and applicable DC-bias derating.
R33 | 10k pullup | Resistor_SMD:R_0603_1608Metric | RC0603FR-0710KL | no | 1 | 5 | VERIFY_STOCK_AND_ASSEMBLY | Verify selected tolerance, voltage/current rating and applicable DC-bias derating.
R34 | 10k pullup | Resistor_SMD:R_0603_1608Metric | RC0603FR-0710KL | no | 1 | 5 | VERIFY_STOCK_AND_ASSEMBLY | Verify selected tolerance, voltage/current rating and applicable DC-bias derating.
R35 | 10k pullup | Resistor_SMD:R_0603_1608Metric | RC0603FR-0710KL | no | 1 | 5 | VERIFY_STOCK_AND_ASSEMBLY | Verify selected tolerance, voltage/current rating and applicable DC-bias derating.
R41 | 0R | Resistor_SMD:R_0402_1005Metric | RC0402JR-070RL | no | 1 | 5 | VERIFY_STOCK_AND_ASSEMBLY | RF starting value; choose RF-rated series/Q/SRF and tune on actual PCB.
R60 | 49.9R 1% | Resistor_SMD:R_0402_1005Metric | RC0402FR-0749R9L | no | 1 | 5 | VERIFY_STOCK_AND_ASSEMBLY | Verify selected tolerance, voltage/current rating and applicable DC-bias derating.
R61 | 49.9R 1% | Resistor_SMD:R_0402_1005Metric | RC0402FR-0749R9L | no | 1 | 5 | VERIFY_STOCK_AND_ASSEMBLY | Verify selected tolerance, voltage/current rating and applicable DC-bias derating.
R70 | 10k | Resistor_SMD:R_0603_1608Metric | RC0603FR-0710KL | no | 1 | 5 | VERIFY_STOCK_AND_ASSEMBLY | Verify selected tolerance, voltage/current rating and applicable DC-bias derating.
R71 | 100k | Resistor_SMD:R_0603_1608Metric | RC0603FR-07100KL | no | 1 | 5 | VERIFY_STOCK_AND_ASSEMBLY | Verify selected tolerance, voltage/current rating and applicable DC-bias derating.
SW1 | RESET | Button_Switch_SMD:SW_Push_1P1T_NO_CK_KMR2 | KMR221GLFS | no | 1 | 5 | VERIFY_STOCK_AND_ASSEMBLY
SW2 | BOOT | Button_Switch_SMD:SW_Push_1P1T_NO_CK_KMR2 | KMR221GLFS | no | 1 | 5 | VERIFY_STOCK_AND_ASSEMBLY
TP1 | GND | TestPoint:TestPoint_Pad_D1.0mm |  | no | 0 | 0 | PCB_FEATURE_NO_PURCHASE
TP2 | VBUS_PROTECTED | TestPoint:TestPoint_Pad_D1.0mm |  | no | 0 | 0 | PCB_FEATURE_NO_PURCHASE
TP3 | +3V3 | TestPoint:TestPoint_Pad_D1.0mm |  | no | 0 | 0 | PCB_FEATURE_NO_PURCHASE
TP4 | SPI_SCLK | TestPoint:TestPoint_Pad_D1.0mm |  | no | 0 | 0 | PCB_FEATURE_NO_PURCHASE
TP5 | SPI_MISO | TestPoint:TestPoint_Pad_D1.0mm |  | no | 0 | 0 | PCB_FEATURE_NO_PURCHASE
TP6 | SPI_MOSI | TestPoint:TestPoint_Pad_D1.0mm |  | no | 0 | 0 | PCB_FEATURE_NO_PURCHASE
TP7 | CC1101_CSN | TestPoint:TestPoint_Pad_D1.0mm |  | no | 0 | 0 | PCB_FEATURE_NO_PURCHASE
TP8 | CC1101_GDO0 | TestPoint:TestPoint_Pad_D1.0mm |  | no | 0 | 0 | PCB_FEATURE_NO_PURCHASE
TP9 | CC1101_GDO2 | TestPoint:TestPoint_Pad_D1.0mm |  | no | 0 | 0 | PCB_FEATURE_NO_PURCHASE
TP10 | RF_SW0 | TestPoint:TestPoint_Pad_D1.0mm |  | no | 0 | 0 | PCB_FEATURE_NO_PURCHASE
TP11 | RF_SW1 | TestPoint:TestPoint_Pad_D1.0mm |  | no | 0 | 0 | PCB_FEATURE_NO_PURCHASE
TP12 | UART_TX_ESP | TestPoint:TestPoint_Pad_D1.0mm |  | no | 0 | 0 | PCB_FEATURE_NO_PURCHASE
U1 | ESP32-WROOM-32E-N8 | RF_Module:ESP32-WROOM-32E | ESP32-WROOM-32E-N8 | no | 1 | 5 | VERIFY_STOCK_AND_ASSEMBLY
U2 | CC1101RGPR | Package_DFN_QFN:Texas_RGP0020H_VQFN-20-1EP_4x4mm_P0.5mm_EP2.4x2.4mm_ThermalVias | CC1101RGPR | no | 1 | 5 | VERIFY_STOCK_AND_ASSEMBLY
U3 | PE42442A-Z | ESP32_CC1101_RF:pSemi_PE42442_QFN24 | PE42442A-Z | no | 1 | 5 | VERIFY_STOCK_AND_ASSEMBLY | 30MHz-6GHz switch; A3 pinout/control only. Datasheet capability does not validate complete RF chain.
U4 | PE42442A-Z | ESP32_CC1101_RF:pSemi_PE42442_QFN24 | PE42442A-Z | no | 1 | 5 | VERIFY_STOCK_AND_ASSEMBLY | 30MHz-6GHz switch; A3 pinout/control only. Datasheet capability does not validate complete RF chain.
U5 | CP2102N-A02-GQFN24 | Package_DFN_QFN:QFN-24-1EP_4x4mm_P0.5mm_EP2.6x2.6mm | CP2102N-A02-GQFN24 | no | 1 | 5 | VERIFY_STOCK_AND_ASSEMBLY
U6 | AP63203WU-7 | ESP32_CC1101_RF:Diodes_TSOT26 | AP63203WU-7 | no | 1 | 5 | VERIFY_STOCK_AND_ASSEMBLY | Fixed 3.3 V buck; input must stay >=3.8 V. 2 A IC rating is NOT USB/board capacity.
U7 | TPS22918DBVR | Package_TO_SOT_SMD:SOT-23-6 | TPS22918DBVR | no | 1 | 5 | VERIFY_STOCK_AND_ASSEMBLY
U8 | SN74LVC2G125DCTR | Package_SO:SSOP-8_2.95x2.8mm_P0.65mm | SN74LVC2G125DCTR | no | 1 | 5 | VERIFY_STOCK_AND_ASSEMBLY
Y1 | ABM8-26.000MHZ-10-1-U-T | ESP32_CC1101_RF:Abracon_ABM8_4Pin_3.2x2.5mm | ABM8-26.000MHZ-10-1-U-T | no | 1 | 5 | VERIFY_STOCK_AND_ASSEMBLY | 26 MHz, four pads, CL 10 pF, ESR 50 ohm; -10 to +60 C part rating. Startup and load trim pending.

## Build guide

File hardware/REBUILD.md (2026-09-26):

# A3 regeneration and verification

Use KiCad 10.0.6 and its matching `pcbnew` Python, plus a separate Python
environment containing `kicad-sch-api==0.5.6` from requirements-eda.txt.
Set KICAD_CLI, KICAD_PYTHON, SCHEMATIC_PYTHON, KICAD_SYMBOL_DIR and
KICAD_FP_ROOT to your installation. Do not use system Python for pcbnew
unless that installation provides it.

## Which board is which?

- `esp32-cc1101-multiband.kicad_pcb`: generated placement seed, intentionally unrouted.
- `A3-critical-routes.kicad_pcb`: manually specified RF/clock/USB/power seed.
- `routing/A3-before-local-finishing.kicad_pcb`: preserved imported router checkpoint.
- `routing/A3-before-crystal-refinement.kicad_pcb`: preserved connected layout before the crystal improvement.
- `A3-routing-candidate.kicad_pcb`: current fully connected review candidate.

Every PCB needs its same-basename .kicad_pro so clearances and minimum
track/drill rules are loaded. Loading a checkpoint without its project can
silently apply different defaults. No file is approved for ordering.

## Rebuild the source capture

Run from the repository root. These commands overwrite generated source
capture/placement files. Preserve any manual edits first.

```sh
set -e
"$SCHEMATIC_PYTHON" hardware/generate_symbols.py
"$SCHEMATIC_PYTHON" hardware/generate_a3_footprints.py
"$SCHEMATIC_PYTHON" hardware/generate_schematic.py
"$KICAD_CLI" sch export netlist --format kicadxml --output hardware/esp32-cc1101-multiband.xml hardware/esp32-cc1101-multiband.kicad_sch
"$KICAD_CLI" sch export netlist --format kicadsexpr --output hardware/esp32-cc1101-multiband.net hardware/esp32-cc1101-multiband.kicad_sch
"$SCHEMATIC_PYTHON" tools/sanitize_netlist_paths.py
"$KICAD_PYTHON" hardware/generate_pcb.py
"$SCHEMATIC_PYTHON" hardware/configure_routing.py
"$SCHEMATIC_PYTHON" hardware/generate_bom.py
"$KICAD_PYTHON" hardware/route_critical.py
```

The finishing step shifts C60 0.4 mm north relative to the placement seed.
The later refinement rotates/moves Y1, moves C31/C32 and reroutes the nearby
clock/power/digital geometry. Neither step changes the schematic. The upstream
placement/critical-route seeds intentionally retain their older geometry.

## Reproduce the final crystal refinement

```sh
"$KICAD_PYTHON" hardware/refine_crystal.py hardware/routing/A3-before-crystal-refinement.kicad_pcb hardware/A3-routing-candidate.kicad_pcb
"$KICAD_CLI" pcb drc --format json --output reports/drc-A3-routing-candidate.json hardware/A3-routing-candidate.kicad_pcb
"$KICAD_PYTHON" hardware/audit_connectivity.py hardware/esp32-cc1101-multiband.xml hardware/A3-routing-candidate.kicad_pcb reports/connectivity-A3.json
"$KICAD_PYTHON" hardware/audit_design.py
"$KICAD_PYTHON" hardware/route_metrics.py
"$KICAD_PYTHON" hardware/audit_routing.py
```

The refinement rejects an input whose SHA-256 differs from the preserved
checkpoint and refuses to overwrite its own input. Expected: 180/180 artifact
checks, 6/6 route screens and native DRC 0 violations / 0 unconnected items.
Regenerated UUIDs may differ; do not claim byte-identical output hashes.

## Reproduce the earlier local finishing step

This overwrites the candidate with the **pre-refinement** state. Run the final
refinement above afterward to restore the current geometry.

```sh
"$KICAD_PYTHON" hardware/finish_routes.py hardware/routing/A3-before-local-finishing.kicad_pcb
"$KICAD_CLI" pcb drc --format json --output reports/drc-A3-routing-candidate.json hardware/A3-routing-candidate.kicad_pcb
"$KICAD_PYTHON" hardware/audit_connectivity.py hardware/esp32-cc1101-multiband.xml hardware/A3-routing-candidate.kicad_pcb reports/connectivity-A3.json
"$KICAD_PYTHON" hardware/audit_routing.py
```

Expected: native DRC 0 violations / 0 unconnected items; parity passes.
Never apply this checkpoint-specific finishing script to a different router
output. It is not a generic autorouter.

For a new router run, use `prepare_routing.py hardware/A3-critical-routes.kicad_pcb`
with KiCad Python. It exports `tmp/A3-route-input.dsn`. The A3 experiment used
Freerouting 2.4.1, In1 disabled for traces, minimum neck 0.15 mm, ordinary
via 0.60/0.30 mm, 0.50 mm copper-to-edge and 0.25 mm hole clearance.
RF/analog/USB are top-only except the already locked USB connector crossover.
Preserve all critical routes; a new session requires fresh finishing/review.
Import with `import_routing.py tmp/new-session.ses hardware/A3-critical-routes.kicad_pcb`.
The shipped final candidate, not a claim of deterministic autorouting, is the
review artifact.

## Recheck and reproduce firmware

```sh
"$KICAD_PYTHON" hardware/audit_design.py
"$KICAD_PYTHON" tools/test_connectivity.py
"$KICAD_PYTHON" tools/test_route_metrics.py
"$SCHEMATIC_PYTHON" tools/test_firmware.py
"$SCHEMATIC_PYTHON" tools/test_preflight.py
"$SCHEMATIC_PYTHON" tools/engineering_budget.py
pio run -d firmware/bringup
"$SCHEMATIC_PYTHON" tools/preflight.py --kicad-cli "$KICAD_CLI" --kicad-python "$KICAD_PYTHON" --output reports/preflight-A3.json
```

Artifact audit now passes on the final candidate: both crystal terminals meet
the unchanged 3.5 mm target. Preflight exits 2 for six pending review categories,
with zero machine-screen failures. It freshly reruns schematic parity, the
artifact audit and route metrics. Input hashes include check/generator code
and firmware sources as well as hardware artifacts.
Do not change a threshold or mark a human review approved to make checks green.
Firmware tests/build are host-only; no hardware is flashed by these commands.

## Design images

Use `kicad-cli sch export svg` for the schematic and `pcb export svg` with
`--layers F.Cu,Edge.Cuts --page-size-mode 2 --exclude-drawing-sheet --mode-single`
for the top routing view. Use `pcb render --rotate '330,0,20'` and set
`--define-var KICAD10_3DMODEL_DIR=...` for the 3D image. These are real KiCad
renders, not product photos. USB/SMA/custom-IC 3D bodies are incomplete.

No Gerbers, purchase orders or paid supplier submissions are generated here.

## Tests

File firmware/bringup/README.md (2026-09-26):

# Bring-up firmware

**A3 hardware only. Do not flash this switch mapping onto A2.** Before fitting
J4, configure/read back the CP2102N's 500 mA bus-powered descriptor with the
shunt removed. Follow the [power setup](../../docs/06-A3-prototype-engineering.md).

This PlatformIO/Arduino program verifies the initial digital hardware without
transmitting RF. It:

1. Configures both RF switches in their all-paths-isolated safe state.
2. Initializes the SPI bus at 1 MHz.
3. Resets the CC1101.
4. Reads PARTNUM and VERSION three times and rejects inconsistent responses.
5. Requires PARTNUM=0x00 and the reviewed VERSION=0x14.
6. Requires two consecutive MARCSTATE=0x01 (IDLE) reads.
7. Lights the status LED only after all these digital checks pass.

It intentionally does not load a modem profile or issue a transmit command.
Full register profiles will be added only after the PCB and regional operating
requirements are verified.

## Diagnostic behavior

Readiness waits have a 5 ms timeout; the IDLE polling window is 20 ms (a final
read may take up to another 5 ms). SPI chip select is released and transactions
are closed on every success/failure path. The manual reset preamble detaches
SPI, sets SCLK high/SI low, pulses CSn, holds it high for 50 us, and restores
SPI mode 0 before SRES. See TI's [CC1101 datasheet](https://www.ti.com/lit/ds/symlink/cc1101.pdf),
sections 19.1.2 and 29.3. Check actual timing on a logic analyzer during bring-up.

Serial output at 115200 baud includes `RESULT`, `PARTNUM`, `VERSION`, and
`MARCSTATE`. Failure strings distinguish readiness timeouts, unstable identity,
unexpected part, unreviewed version and an IDLE timeout. A value of `0xFF` may
mean that a field was never read; use `RESULT`, not the raw fields alone.
Other versions, including older 0x04 parts, require review; rejection does not
prove a counterfeit. The old all-zero-bus false-positive has been removed.

The unused, unguarded path-selection helper was removed. There is no command
interface that can select an RF branch, enter RX/TX, or write a modem profile.
Five external 10 kohm pullups remain necessary during reset and before code runs.
GPIO4 is the shared RF disable; GPIO32/33 select U3 and GPIO16/17 select U4.
The startup helper preloads all five outputs HIGH before enabling their output
drivers. PE42442 state 111 is isolated; 000 is not. Additional host tests check
the exact A3 pin map, output preload ordering and re-isolation ordering.
Passing diagnostics does not establish sensitivity, crystal accuracy, RF
isolation, emissions compliance or hardware reliability.

## Reproduce software checks

```sh
python3 tools/test_firmware.py
pio run -d firmware/bringup
```

Run from the repository root. The host tests require Python 3 and a C++11
compiler (`CXX` may override `c++`); they compile the same diagnostic header used
by the ESP32. Seventeen scenarios cover normal/repeated operation, stuck buses,
identity mismatch, reset/read timeouts, unstable/non-IDLE states and timer wrap.
They check SPI command boundaries and transaction cleanup, not actual electrical
timing or the Arduino peripheral driver. No board is flashed by these commands.

The tested PlatformIO platform is pinned to `espressif32@7.1.3`; resolved
framework/tool versions are recorded in the [checkpoint report](../../reports/overnight-checkpoint-2026-09-23.md).
This is not a complete dependency lockfile.

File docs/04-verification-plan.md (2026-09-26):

# Rev A Verification Plan

No manufacturing order should be placed until all pre-order gates are checked.

## A3 current checkpoint — 2026-09-26

The routed A3 candidate has zero native DRC violations and zero unconnected
items. See [A3 engineering decisions and bench acceptance](06-A3-prototype-engineering.md)
and [fresh preflight](../reports/preflight-A3.json). The refined crystal layout
now passes the unchanged placement target; all 180 artifact checks and six
route screens pass. See the [refinement evidence](../reports/autonomous-refinement-A3-2026-09-26.md).
Six independent/supplier review categories remain pending. No physical tests
have occurred and no order is authorized by these reports.

## A2 historical checkpoint — 2026-09-22

- [x] Replace the incompatible crystal placeholder with an exact four-pad
  26 MHz part, manufacturer land pattern and documented initial load calculation.
- [x] Resolve the four USB hole-clearance errors by selecting HRO TYPE-C-31-M-12.
- [x] Fresh main-design ERC: 0 violations; placement DRC: 0 violations,
  217 unconnected items; targeted audit: 115/115 pass.
- [x] Produce a separate partial-routing candidate and run native DRC:
  0 violations, 23 unconnected items. It is NOT the approved main layout.
- [x] Add proposed exact parts for 63 of 81 populated BOM positions.
- [ ] Finish and review routing, including 35 candidate power segments narrower
  than the 0.40 mm target, USB coupling, RF geometry and return paths.
- [ ] Select the remaining 18 populated parts and verify sourcing for all parts.
- [ ] Close thermal, USB-power and low-band RF-switch acceptance gates.

See `05-A2-routing-and-validation.md` for the stackup target and tests.

## A1 historical correction checkpoint — 2026-09-22

- [x] Correct DGUARD, balun top-view pad mapping, LED polarity and D2 package.
- [x] Correct CP2102N supply/sense circuit and add local bypass capacitors.
- [x] Correct USB connector orientation and actual ESP32 antenna overhang.
- [x] Replace regulator package and add initial thermal/ground copper.
- [x] Run fresh ERC (0 violations) and targeted artifact audit (107/107 pass).
- [x] Generate a BOM inventory covering all 103 schematic footprints.
- [ ] Resolve J1's four 0.1944 mm hole-clearance errors against the chosen fab.
- [ ] Complete power/signal routing (215 unconnected items remain).
- [ ] Approve every exact BOM part; verify load profile, thermal behavior,
      USB current availability and low-band switch performance.

The checked corrections do not close the independent pre-order gates below.

## Pre-order schematic gates

- [ ] Confirm every ESP32-WROOM-32E pin against the current datasheet.
- [ ] Confirm EN and GPIO0 timing against the Espressif reference circuit.
- [ ] Confirm CP2102N power configuration and DTR/RTS polarity.
- [ ] Confirm independent 5.1 kohm USB-C CC resistors.
- [ ] Confirm USB ESD device orientation and pinout.
- [ ] Confirm regulator stability, capacitor ESR requirements, and worst-case
      thermal dissipation.
- [ ] Confirm all CC1101 supply pins and exposed pad connections.
- [ ] Confirm CC1101 crystal load calculation using the selected crystal.
- [ ] Confirm broadband balun footprint and orientation against manufacturer
      land pattern.
- [ ] Confirm both SP3T switch pinouts, logic thresholds, truth table, and
      power-up state.
- [ ] Independently trace all three RF branches from CC1101 to SMA.
- [ ] Confirm SMA gender and center-pin footprint with the exact ordered part.
- [ ] Run KiCad ERC with zero unexplained errors.

## Pre-order PCB gates

- [ ] Obtain the board house's actual four-layer stackup.
- [ ] Calculate 50-ohm grounded coplanar-waveguide geometry for that stackup.
- [ ] Confirm ESP32 antenna keepout on all layers.
- [ ] Confirm no digital trace crosses the CC1101/RF region.
- [ ] Review return-current paths for USB, SPI, crystal, and RF controls.
- [ ] Confirm thermal copper for the 3.3 V regulator.
- [ ] Confirm CC1101 exposed-pad paste aperture and ground vias.
- [ ] Check RF component orientation visually against the reference design.
- [ ] Run DRC with zero unexplained errors.
- [ ] Render front/back/3D views and perform a mechanical review.
- [ ] Print the board at 1:1 scale and physically compare USB and SMA parts.
- [ ] Verify all BOM parts are orderable and not end-of-life.
- [ ] Verify all assembly-side orientations in the pick-and-place file.

## First power-up

- [ ] Power from a current-limited 5 V bench supply before connecting USB data.
- [ ] Confirm no short between 5 V, 3.3 V, and GND.
- [ ] Confirm 3.3 V regulation and idle current.
- [ ] Confirm EN rises cleanly and the ESP32 produces UART boot output.
- [ ] Flash `firmware/bringup` and verify LEDs and switch truth table.
- [ ] Read plausible CC1101 PARTNUM and VERSION status registers.
- [ ] Verify SPI waveform and chip-ready timing with a logic analyzer.
- [ ] Confirm the CC1101 remains idle during RF path changes.

## RF validation

- [ ] Use a 50-ohm termination whenever an antenna is not installed.
- [ ] Measure each branch with a VNA or arrange measurement through an RF lab.
- [ ] Tune DNP matching footprints as required on the assembled PCB.
- [ ] Measure conducted output power and harmonics into a suitable attenuator.
- [ ] Test receive sensitivity with a known signal source where possible.
- [ ] Perform over-the-air range tests using the correct antenna for each band.
- [ ] Confirm firmware power settings remain inside the applicable regional
      rules before any non-shielded transmit testing.

## Rev A disposition

- [ ] Record every rework and measurement.
- [ ] Promote unchanged design to Rev B only if all critical checks pass.
- [ ] Otherwise update schematic, layout, BOM, and test plan before reordering.

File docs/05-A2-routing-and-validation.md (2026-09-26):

# A2 routing and validation constraints

**Historical A2 analysis, superseded for the current board.** See
[A3 engineering decisions](06-A3-prototype-engineering.md). Do not apply A2
power or switch decisions to A3.

Status: engineering draft, not fabrication approval. No order has been placed.

## Stackup target

Use JLCPCB **JLC04161H-7628**, nominal 1.6 mm four-layer, as the current
design target, not a purchase commitment. Confirm the exact stackup with the
fabricator before release. The published sequence is:

| Layer | Material / nominal thickness | Function |
|---|---|---|
| F.Cu | 0.035 mm copper | Components, RF, USB, local bypass loops |
| Dielectric 1 | 7628 prepreg, 0.2104 mm | RF reference-plane spacing |
| In1.Cu | 0.0152 mm copper | Continuous GND; no signal routing |
| Core | 1.065 mm | FR-4 |
| In2.Cu | 0.0152 mm copper | Power and slow digital signals |
| Dielectric 2 | 7628 prepreg, 0.2104 mm | Bottom reference spacing |
| B.Cu | 0.035 mm copper | Digital signals and GND |

These are nominal laminate values, not a thickness-tolerance guarantee. The
main board currently carries a nominal 1.6 mm thickness; it does **not** yet
contain a approved controlled-impedance stackup or manufacturing coupon.
[Fabricator stackups](https://jlcpcb.com/impedance).

## Routing rules and limitations

The project defines Default, POWER, USB, RF_LOCAL and ANALOG_LOCAL classes.
Default trace width is 0.20 mm; power target width is 0.40 mm. The 0.15 mm
minimum allows local fine-pitch escapes; it is not an acceptable long power
trunk. Existing 0.25 mm hole-clearance rules remain, with no DRC exclusions.
These dimensions fit within the published prototype capabilities, but assembly
and impedance approval are separate. [Fabrication capabilities](https://jlcpcb.com/capabilities/Capab).

The local routing experiment constrains RF, crystal/bias/decoupling and USB
nets to F.Cu and leaves In1.Cu unavailable for traces. Its 0.20 mm RF/USB
widths are placeholders, **not calculated 50-ohm / 90-ohm geometry**.
Autorouting does not establish differential-pair coupling, filter behavior,
short bypass loops or an adequate power distribution network.

Before promoting any candidate:

1. Manually route the RF path and its ground returns. Solve the final 50-ohm
   SMA/feed geometry with actual dielectric data, mask, copper thickness and
   coplanar gap; obtain fabricator confirmation. Keep matching-network segments
   compact and include their parasitics in tuning.
2. Route USB D+/D- as a consistent 90-ohm differential pair, with short symmetric
   connector joins and ESD connections. Check skew, stubs and continuous ground.
3. Keep clock traces short; no fast digital routes beneath the crystal or RF
   network. Add appropriately placed ground stitching and return vias.
4. Review every sub-0.40 mm power segment. Permit only documented short escapes;
   calculate voltage drop using final copper, length and peak load.
5. Run native KiCad DRC and connectivity with the candidate's matching project
   settings. Zero shorts/clearance errors alone does not mean routing is complete.

## Crystal

Y1 is Abracon **ABM8-26.000MHZ-10-1-U-T**: 26 MHz, CL 10 pF,
ESR 50 ohms, four pads. Pins 1/3 are the oscillator terminals; 2/4 are ground.
Its -10 to +60 C rating limits the currently selected component set; this is
not an industrial-temperature-qualified board. [Exact part](https://abracon.com/parametric/crystals/ABM8-26.000MHZ-10-1-U-T),
[package drawing](https://abracon.com/Resonators/abm8.pdf).

C31=C32=15 pF C0G is the starting load: CL = 15/2 + 2.5 = 10 pF,
using TI's typical total parasitic capacitance. Actual PCB/pin parasitics are
not yet measured. Verify startup over supply/temperature, aging/tolerance budget
and carrier frequency with a calibrated instrument, then trim capacitors if
needed. Do not directly probe the crystal with a high-capacitance probe.
[CC1101 datasheet, sections 4.4 and 7.3](https://www.ti.com/lit/ds/symlink/cc1101.pdf).

## Power and temperature: unresolved acceptance gate

The AP7361C's 1 A headline rating does not establish board load capacity.
Screening at 5.25 V input, 3.267 V output and 40 C ambient, using the
datasheet's typical 110 C/W SOT-223 thermal resistance, gives approximately:

| Continuous load | LDO dissipation | Estimated junction temperature |
|---|---:|---:|
| 0.10 A | 0.198 W | 62 C |
| 0.30 A | 0.595 W | 105 C |
| 0.50 A | 0.992 W | 149 C |

This simplified calculation excludes small quiescent losses and is **not** a
prediction validated for this copper layout. The 500 mA case has inadequate
margin. Prototype testing must establish an allowed sustained load; neither
300 mA nor 500 mA is currently an approved board rating. If the intended Wi-Fi
and radio workload cannot meet the thermal target, redesign the supply as a
buck regulator before release. [Regulator datasheet](https://www.diodes.com/datasheet/download/AP7361C.pdf).

Test procedure after a reviewed board exists:

- Start on a current-limited bench supply with ESP32 held reset; check rail
  voltage and unexpected current before releasing reset.
- Test 4.75/5.0/5.25 V input, idle, boot, Wi-Fi burst and combined radio load.
  Capture 3.3 V at the ESP32 and CC1101 with an oscilloscope. Include cable,
  fuse, bead and trace voltage drops; check brownout and oscillator startup.
- Log input current, ambient, regulator/tab temperature and warm-up until
  steady state. Estimate junction temperature with an appropriate board model,
  not case temperature alone. Use a provisional design target <=110 C junction.
- Check capacitor effective values at DC bias, not nominal markings only.
- Verify USB source-current availability/enumeration behavior. CC resistors and
  a 500 mA PTC are not current negotiation or a startup power controller.

## RF acceptance gates

315/433/868/915 MHz remain supported **design targets**, not measured claims.
The selected switch's tabulated RF performance does not guarantee the lower
two bands. Measure insertion loss, return loss and isolation of each path with
a calibrated VNA. Measure the shared upper branch at both 868 and 915 MHz.
Then verify conducted sensitivity, output spectrum/harmonics and frequency
accuracy with appropriate equipment. Use RF terminations/attenuation and a
shielded setup; no unrestricted over-the-air transmit tests.

If 315/433 MHz performance fails, select a switch explicitly characterized for
those bands and re-evaluate its footprint, logic and matching. Firmware cannot
repair an unsuitable analog RF path. Keep the default 00 isolation state and
CC1101 IDLE during all switch changes. Current bring-up firmware does not TX.

## Purchasing status

The BOM remains a draft. Proposed exact parts have been added for the USB/SMA
connectors, crystal, fuse, bead, RF inductors and many passives. Unselected items
remain explicitly marked SELECT_EXACT_PART. All populated rows still need a
stock/lifecycle check, approved assembly sourcing and suitable spares. Five-unit
quantities exclude spares. Do not substitute M-12A/B/C for HRO's base M-12
connector without reviewing that variant's drawing.

Primary part references:

- [HRO connector](https://en.krhro.com/Product-Details/726.html), base M-12
  drawing sheet 4 (local reviewed copy: `tmp/pdfs/hro-official.pdf`).
- [Amphenol 132134](https://www.amphenolrf.com/en-us/part/132134/662/), standard
  SMA female, straight through-hole; final drawing/physical-fit check pending.
- [Coilcraft 0402HP](https://www.coilcraft.com/getmedia/54459dcc-b821-4a9d-b91e-0416ea86a9b2/0402hp.pdf),
  selected 5% RF inductors; values are starting values pending PCB tuning.
- [Bourns MF-NSMF](https://www.bourns.com/docs/product-datasheets/mf-nsmf.pdf),
  MF-NSMF050-2, 1206, 0.5 A hold at 23 C, 13.2 V; apply temperature derating.
- [Murata bead](https://www.murata.com/en-us/api/pdfdownloadapi?cate=cgsubChipFerriBead&partno=BLM18AG601SN1%23),
  [100 nF bypass](https://search.murata.co.jp/Ceramy/image/img/A01X/G101/ENG/GRM155R71C104KA88-01.pdf).
- Yageo exact spec sheets use `https://www.yageogroup.com/component-documentation/download/specsheet/`
  followed by the BOM part number; for example [10 kohm 0603](https://www.yageogroup.com/component-documentation/download/specsheet/RC0603FR-0710KL).

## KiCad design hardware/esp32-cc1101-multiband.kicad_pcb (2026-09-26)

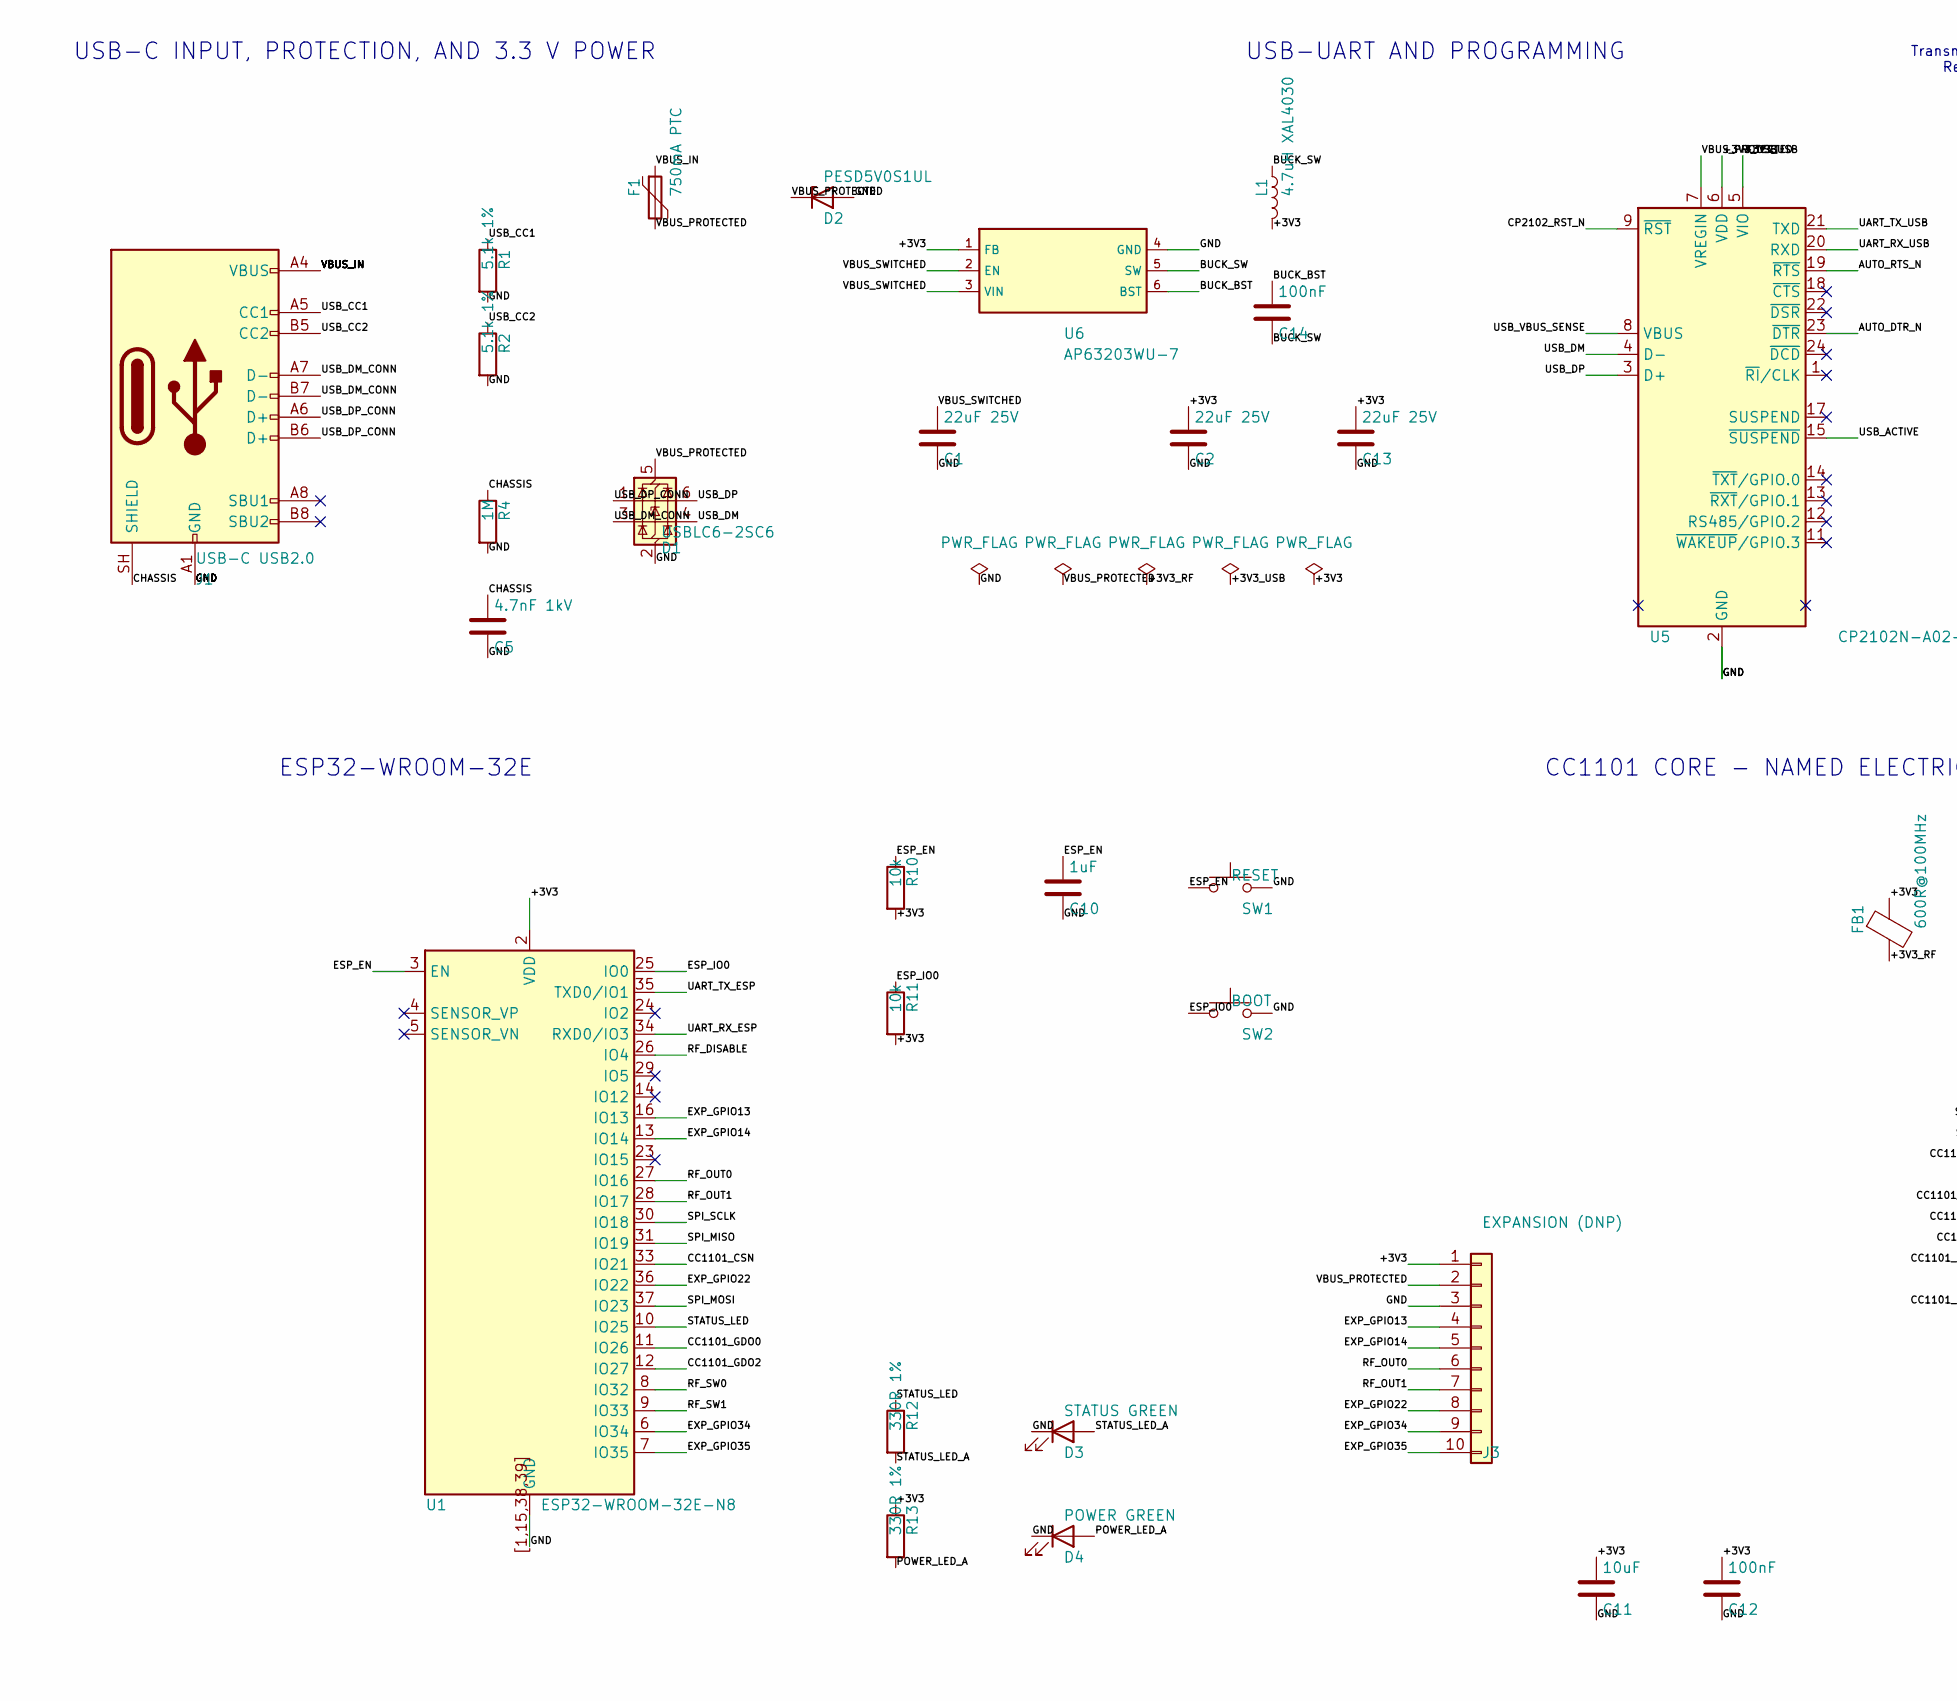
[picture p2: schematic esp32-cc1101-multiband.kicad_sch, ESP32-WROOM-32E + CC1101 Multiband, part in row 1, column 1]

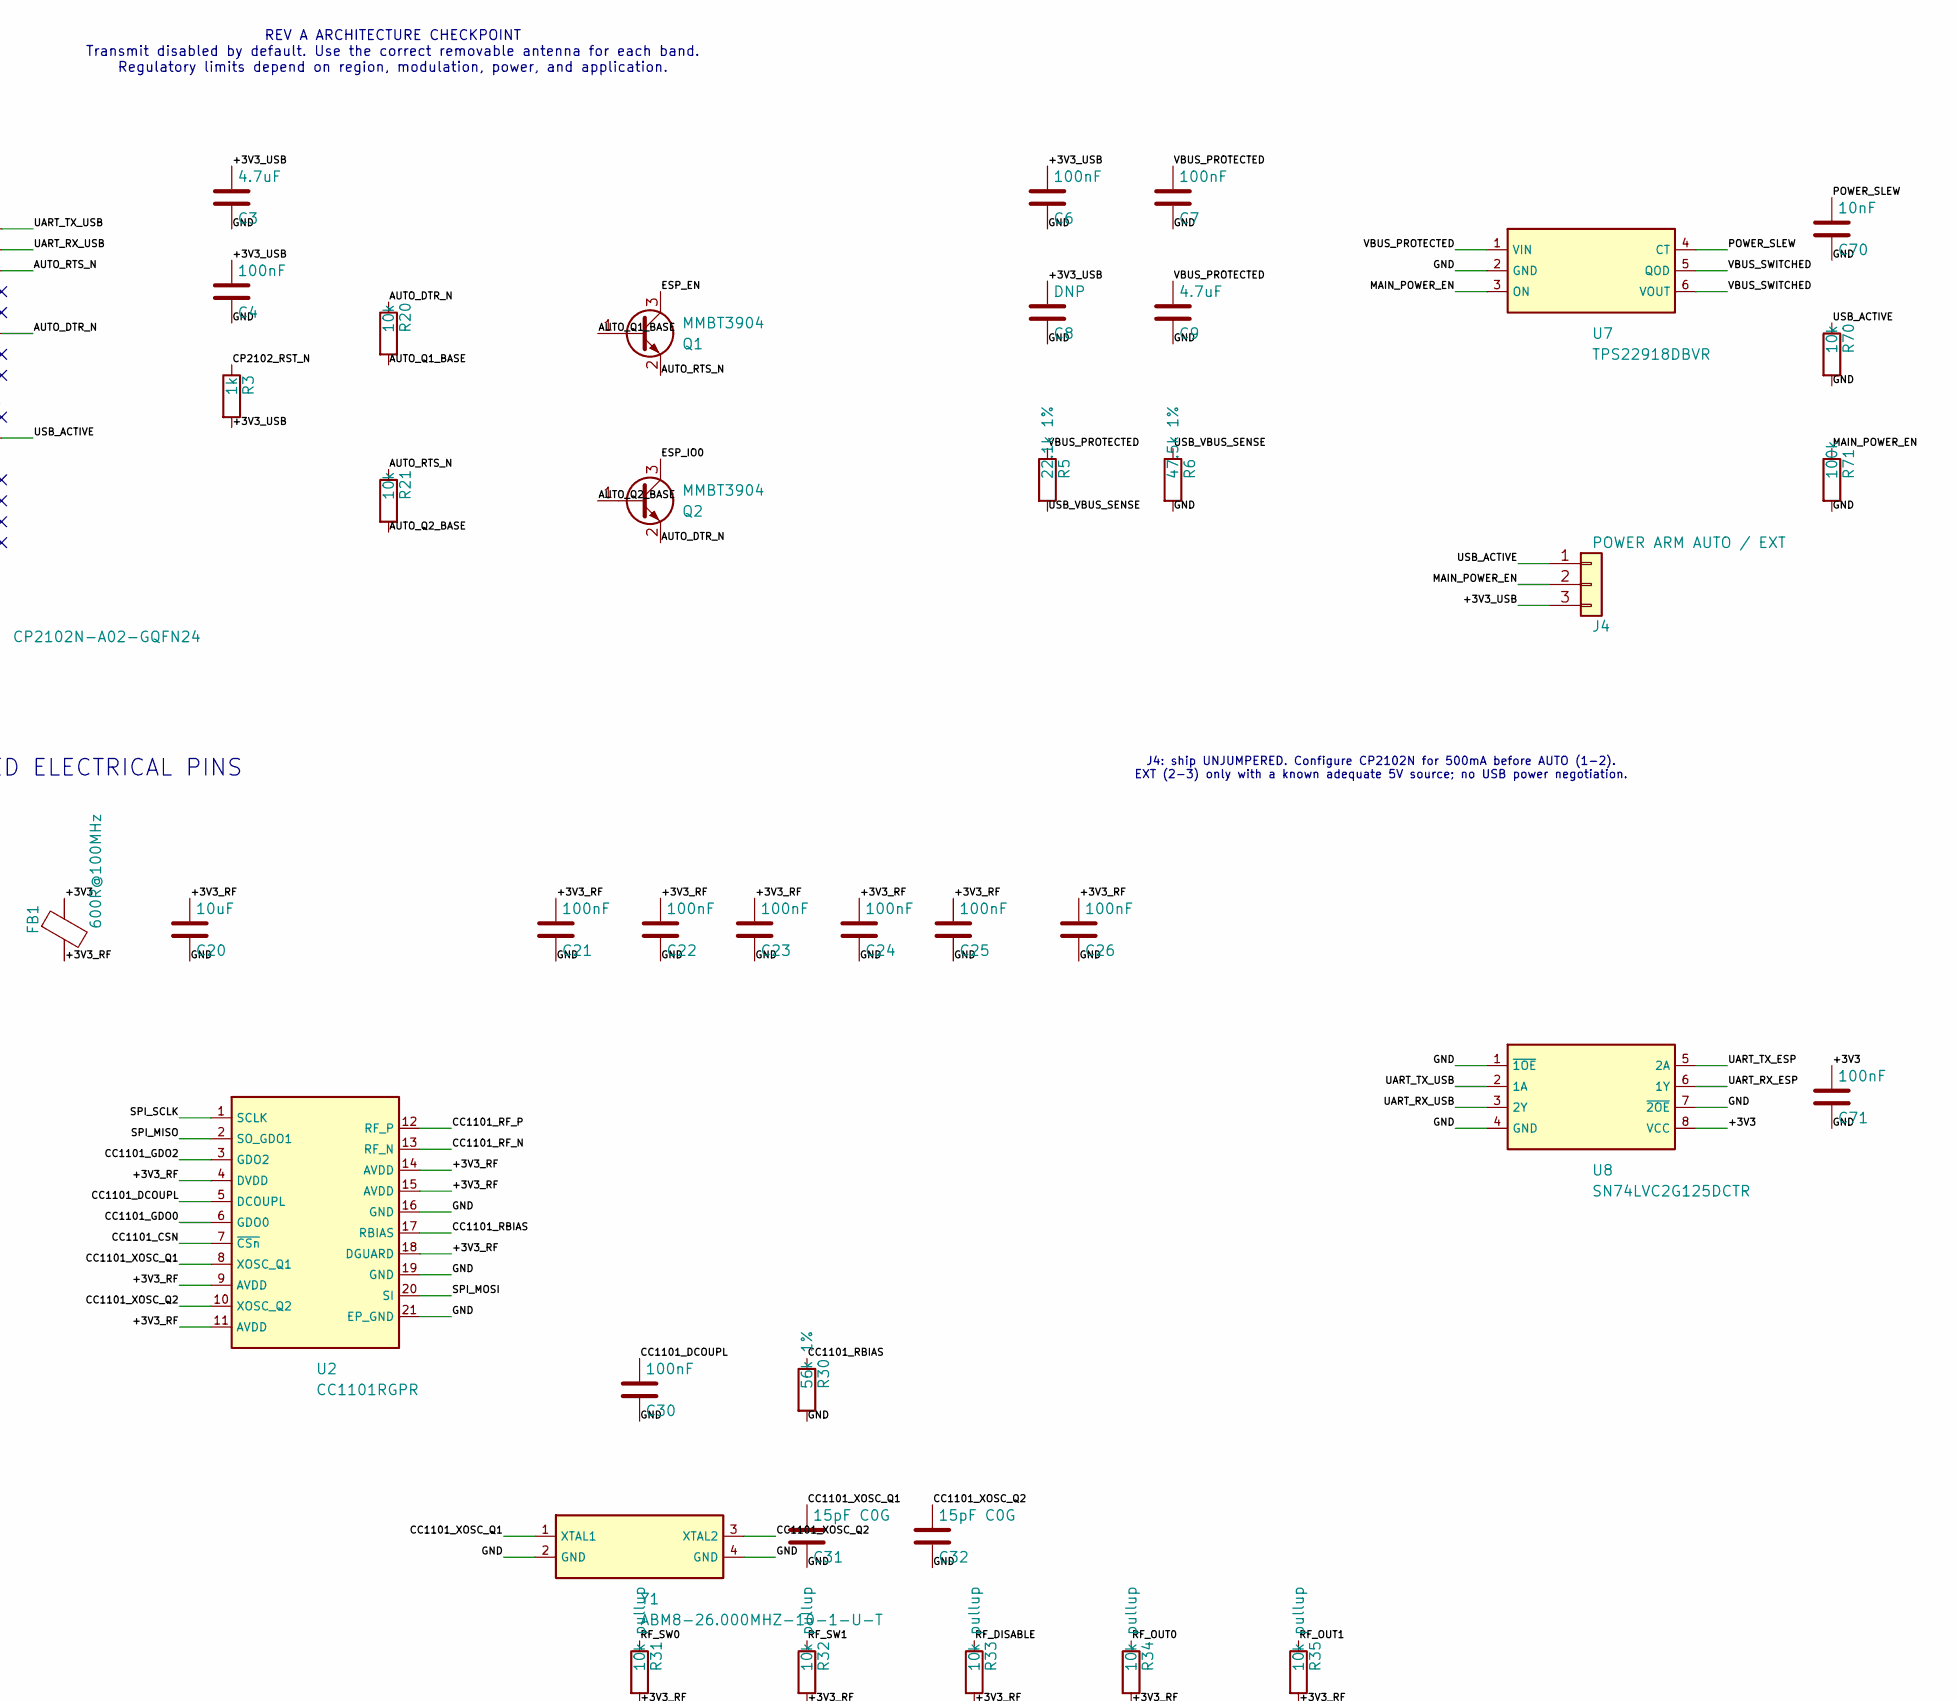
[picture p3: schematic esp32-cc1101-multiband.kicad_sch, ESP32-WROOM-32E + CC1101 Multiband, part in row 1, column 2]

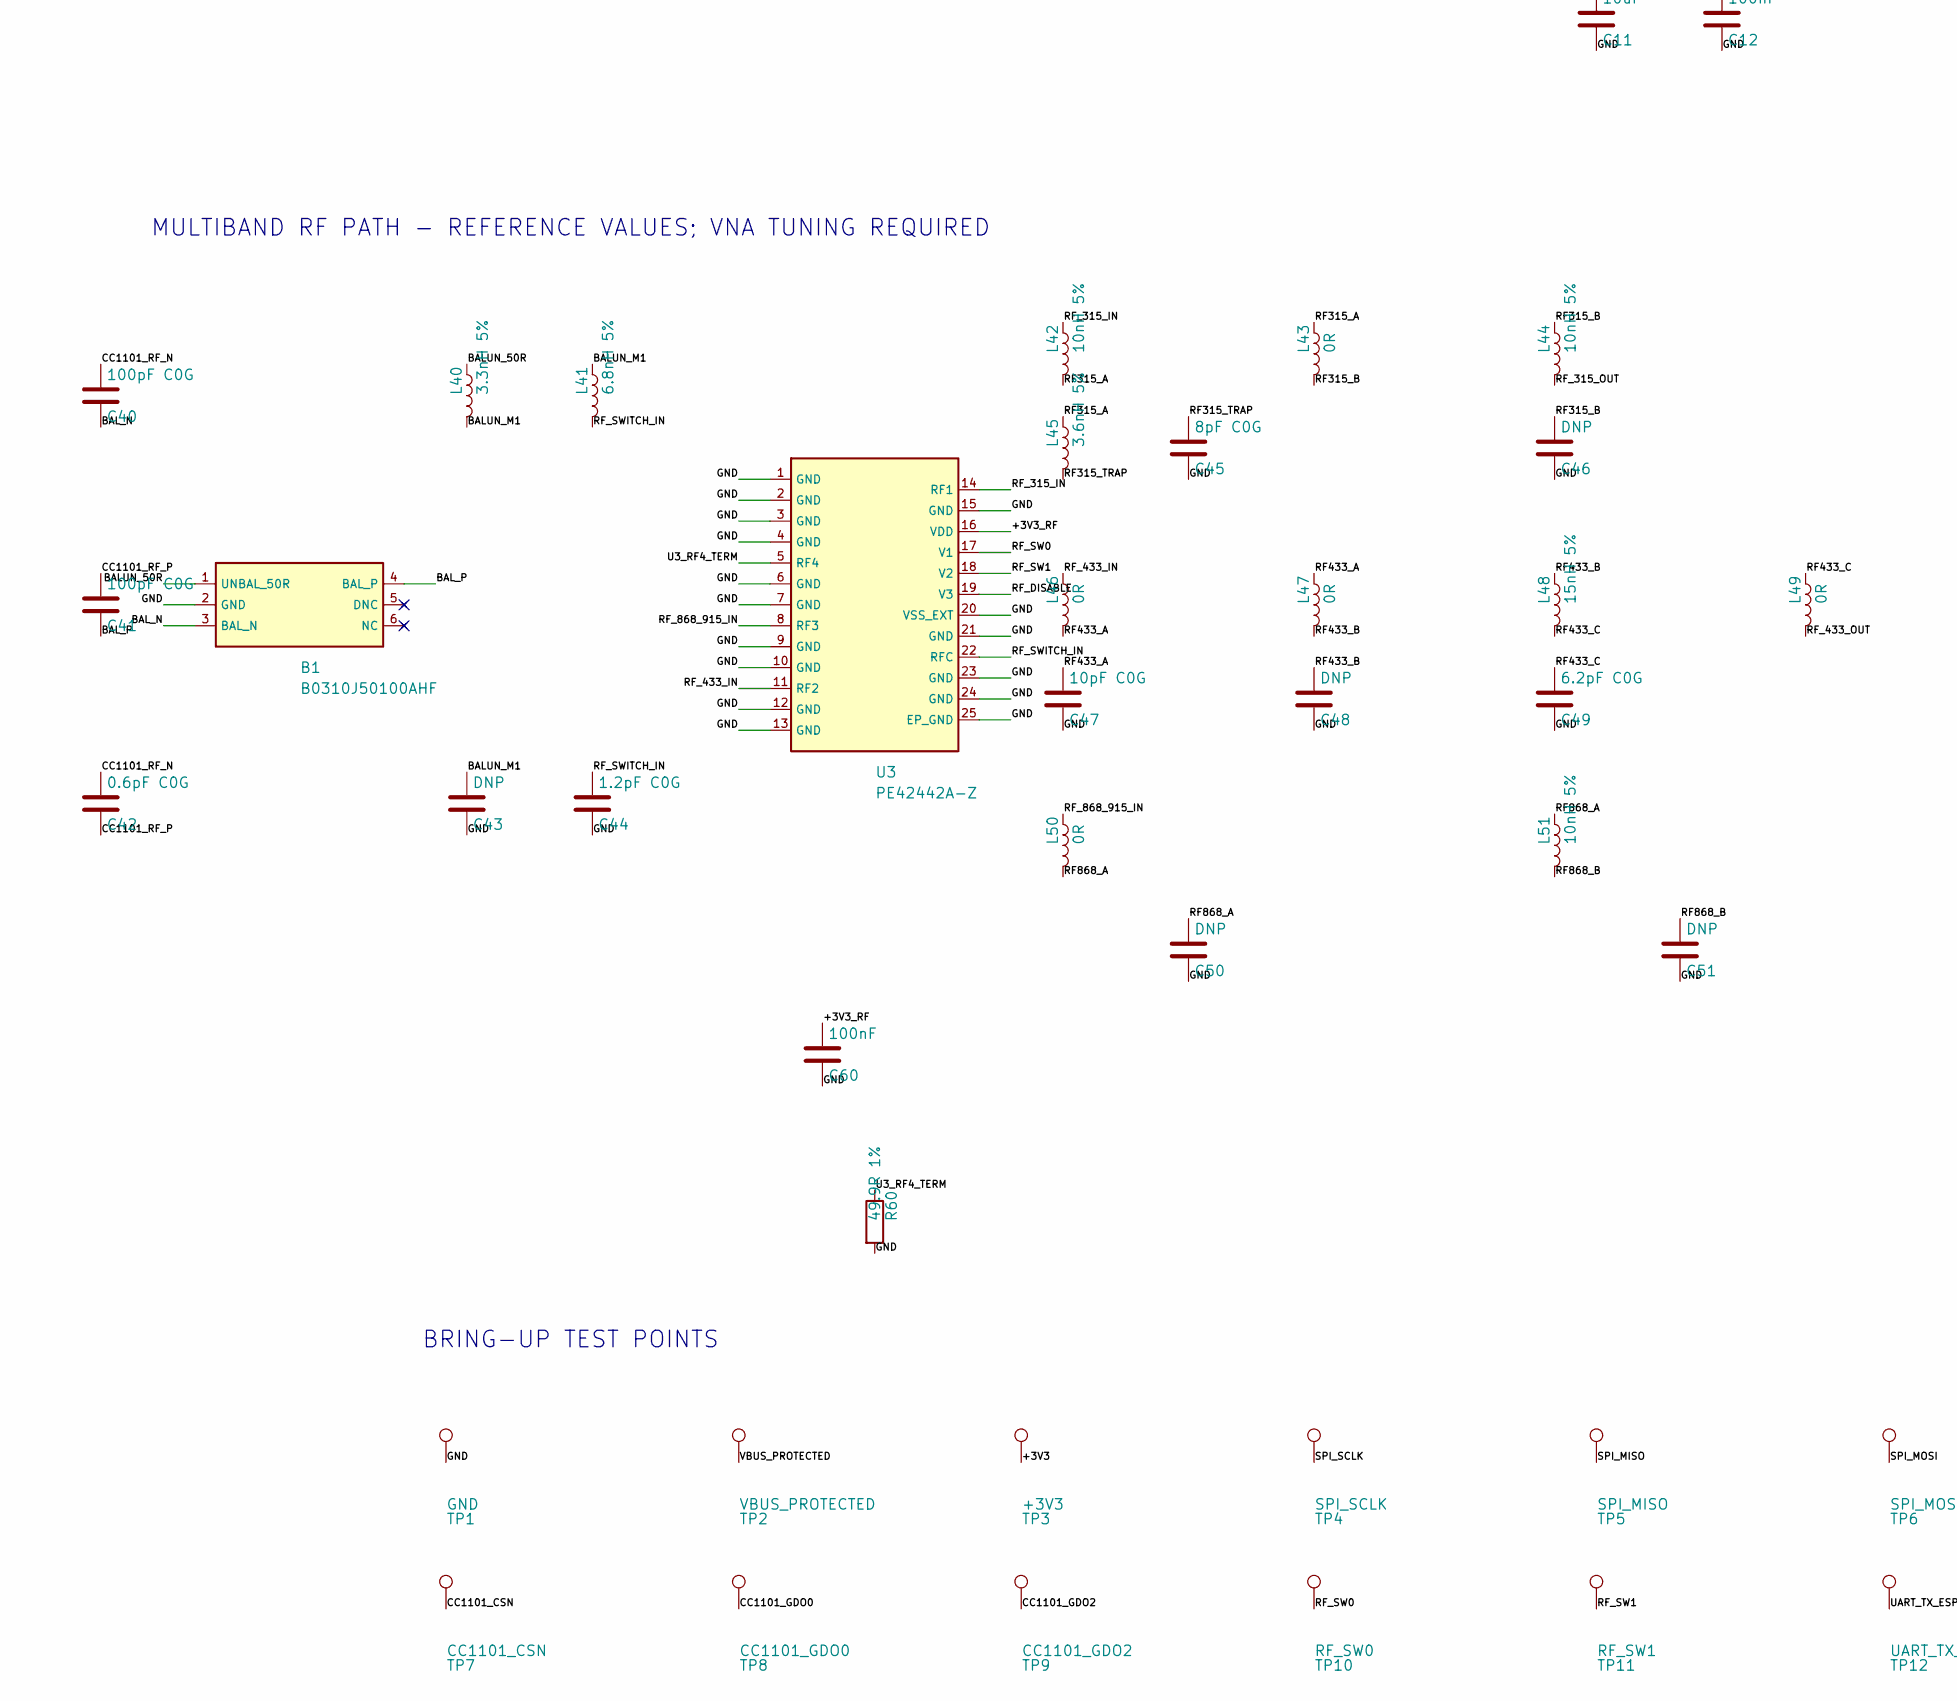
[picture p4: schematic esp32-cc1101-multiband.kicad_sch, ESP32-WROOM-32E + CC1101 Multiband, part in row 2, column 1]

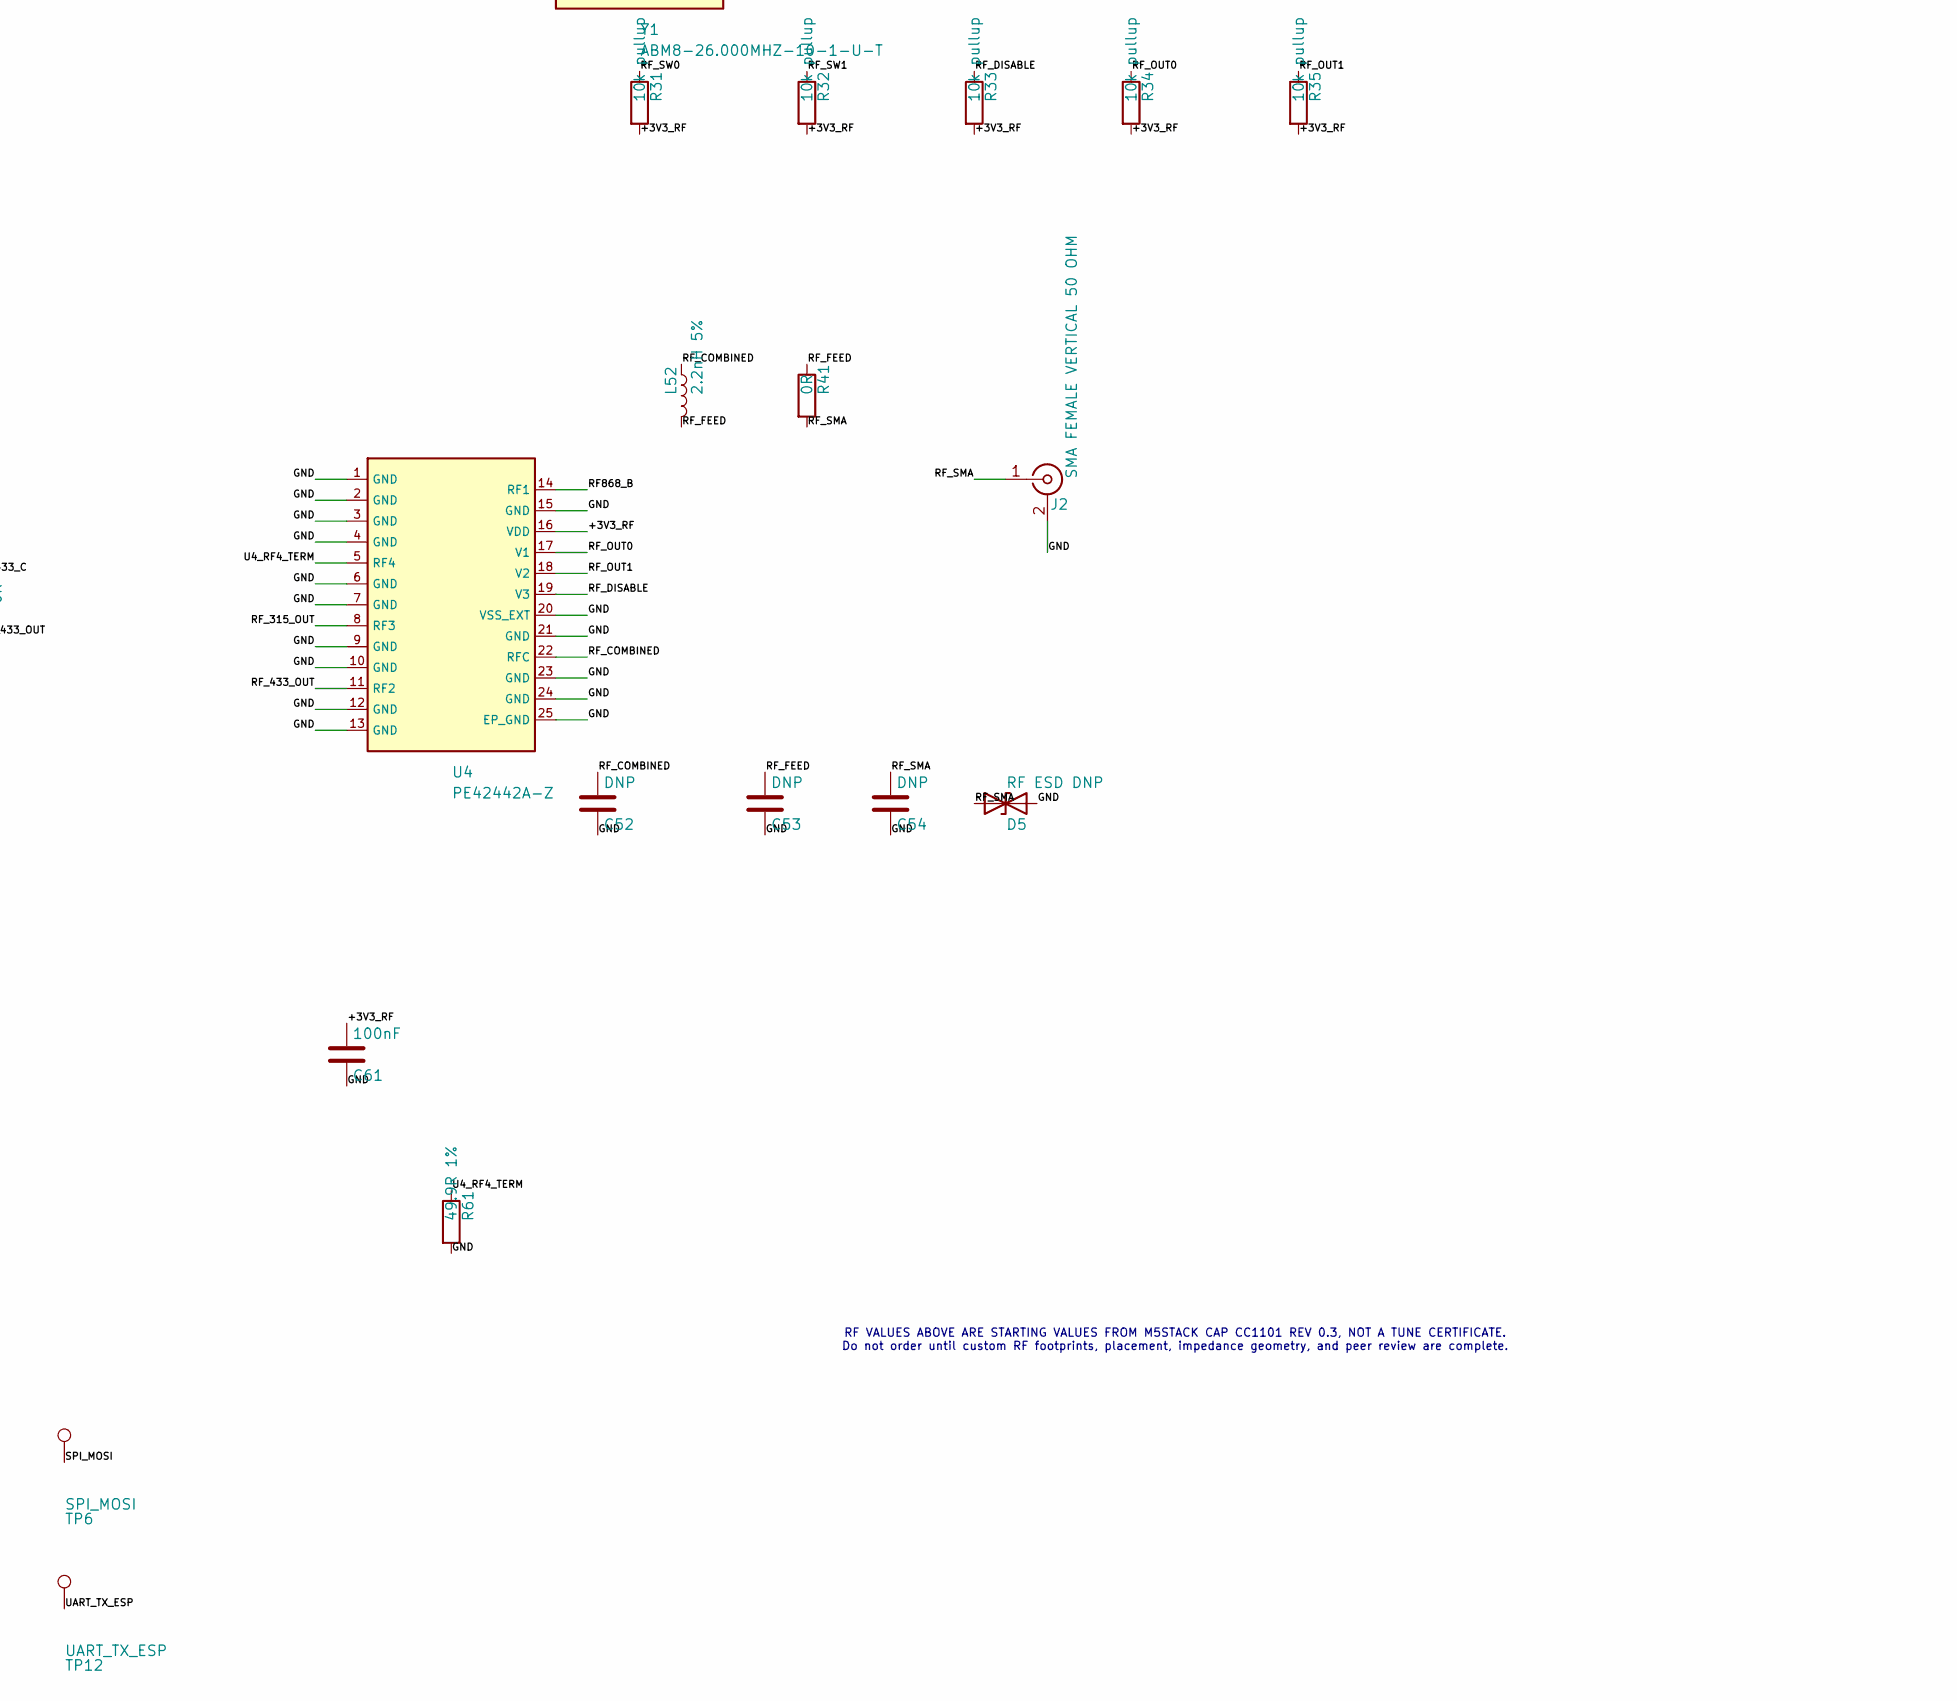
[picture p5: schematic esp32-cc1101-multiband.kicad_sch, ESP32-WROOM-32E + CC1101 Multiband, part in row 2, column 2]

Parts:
B1: B0310J50100AHF; TTM_B0310J50100AHF
C1, C2, C13: 22uF 25V; C_1206_3216Metric
C3, C9: 4.7uF; C_0603_1608Metric
C4, C6, C7, C12, C14, C21, C22, C23, C24, C25, C26, C30, C60, C61, C71: 100nF; C_0402_1005Metric
C5: 4.7nF 1kV; C_1206_3216Metric
C8: DNP; C_0603_1608Metric
C10: 1uF; C_0603_1608Metric
C11, C20: 10uF; C_0603_1608Metric
C31, C32: 15pF C0G; C_0402_1005Metric
C40, C41: 100pF C0G; C_0402_1005Metric
C42: 0.6pF C0G; C_0402_1005Metric
C43, C46, C48, C50, C51, C52, C53, C54: DNP; C_0402_1005Metric
C44: 1.2pF C0G; C_0402_1005Metric
C45: 8pF C0G; C_0402_1005Metric
C47: 10pF C0G; C_0402_1005Metric
C49: 6.2pF C0G; C_0402_1005Metric
C70: 10nF; C_0402_1005Metric
D1: USBLC6-2SC6; SOT-23-6
D2: PESD5V0S1UL; D_SOD-882
D3: STATUS GREEN; LED_0603_1608Metric
D4: POWER GREEN; LED_0603_1608Metric
D5: RF ESD DNP; D_0402_1005Metric
F1: 750mA PTC; Fuse_1206_3216Metric
FB1: 600R@100MHz; L_0603_1608Metric
J1: USB-C USB2.0; USB_C_Receptacle_HRO_TYPE-C-31-M-12
J2: SMA FEMALE VERTICAL 50 OHM; SMA_Amphenol_132134_Vertical
J3: EXPANSION (DNP); PinHeader_1x10_P2.54mm_Vertical
J4: POWER ARM AUTO / EXT; PinHeader_1x03_P2.54mm_Vertical
L1: 4.7uH XAL4030; L_Coilcraft_XAL4030-XXX
L40: 3.3nH 5%; L_0402_1005Metric
L41: 6.8nH 5%; L_0402_1005Metric
L42, L44, L51: 10nH 5%; L_0402_1005Metric
L43, L46, L47, L49, L50: 0R; L_0402_1005Metric
L45: 3.6nH 5%; L_0402_1005Metric
L48: 15nH 5%; L_0402_1005Metric
L52: 2.2nH 5%; L_0402_1005Metric
PWR1, PWR2, PWR3, PWR4, PWR5: PWR_FLAG
Q1, Q2: MMBT3904; SOT-23
R1, R2: 5.1k 1%; R_0603_1608Metric
R3: 1k; R_0603_1608Metric
R4: 1M; R_0603_1608Metric
R5: 22.1k 1%; R_0603_1608Metric
R6: 47.5k 1%; R_0603_1608Metric
R10, R11, R20, R21, R70: 10k; R_0603_1608Metric
R12, R13: 330R 1%; R_0603_1608Metric
R30: 56k 1%; R_0402_1005Metric
R31, R32, R33, R34, R35: 10k pullup; R_0603_1608Metric
R41: 0R; R_0402_1005Metric
R60, R61: 49.9R 1%; R_0402_1005Metric
R71: 100k; R_0603_1608Metric
SW1: RESET; SW_Push_1P1T_NO_CK_KMR2
SW2: BOOT; SW_Push_1P1T_NO_CK_KMR2
TP1: GND; TestPoint_Pad_D1.0mm
TP2: VBUS_PROTECTED; TestPoint_Pad_D1.0mm
TP3: +3V3; TestPoint_Pad_D1.0mm
TP4: SPI_SCLK; TestPoint_Pad_D1.0mm
TP5: SPI_MISO; TestPoint_Pad_D1.0mm
TP6: SPI_MOSI; TestPoint_Pad_D1.0mm
TP7: CC1101_CSN; TestPoint_Pad_D1.0mm
TP8: CC1101_GDO0; TestPoint_Pad_D1.0mm
TP9: CC1101_GDO2; TestPoint_Pad_D1.0mm
TP10: RF_SW0; TestPoint_Pad_D1.0mm
TP11: RF_SW1; TestPoint_Pad_D1.0mm
TP12: UART_TX_ESP; TestPoint_Pad_D1.0mm
U1: ESP32-WROOM-32E-N8; ESP32-WROOM-32E
U2: CC1101RGPR; Texas_RGP0020H_VQFN-20-1EP_4x4mm_P0.5mm_EP2.4x2.4mm_Thermal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
U3, U4: PE42442A-Z; pSemi_PE42442_QFN24
U5: CP2102N-A02-GQFN24; QFN-24-1EP_4x4mm_P0.5mm_EP2.6x2.6mm
U6: AP63203WU-7; Diodes_TSOT26
U7: TPS22918DBVR; SOT-23-6
U8: SN74LVC2G125DCTR; SSOP-8_2.95x2.8mm_P0.65mm
Y1: ABM8-26.000MHZ-10-1-U-T; Abracon_ABM8_4Pin_3.2x2.5mm

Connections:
/+3V3: C2.1, C11.1, C12.1, C13.1, C71.1, FB1.1, J3.1, L1.2, PWR5.1, R10.2, R11.2, R13.1, TP3.1, U1.2 (VDD), U6.1 (FB), U8.8 (VCC)
/+3V3_RF: C20.1, C21.1, C22.1, C23.1, C24.1, C25.1, C26.1, C60.1, C61.1, FB1.2, PWR3.1, R31.2, R32.2, R33.2, R34.2, R35.2, U2.4 (DVDD), U2.9 (AVDD), U2.11 (AVDD), U2.14 (AVDD), U2.15 (AVDD), U2.18 (DGUARD), U3.16 (VDD), U4.16 (VDD)
/+3V3_USB: C3.1, C4.1, C6.1, C8.1, J4.3, PWR4.1, R3.2, U5.5 (VIO), U5.6 (VDD)
/AUTO_DTR_N: Q2.2 (E), R20.1, U5.23 (~DTR)
/AUTO_Q1_BASE: Q1.1 (B), R20.2
/AUTO_Q2_BASE: Q2.1 (B), R21.2
/AUTO_RTS_N: Q1.2 (E), R21.1, U5.19 (~RTS)
/BALUN_50R: B1.1 (UNBAL_50R), L40.1
/BALUN_M1: C43.1, L40.2, L41.1
/BAL_N: B1.3 (BAL_N), C40.2
/BAL_P: B1.4 (BAL_P), C41.2
/BUCK_BST: C14.1, U6.6 (BST)
/BUCK_SW: C14.2, L1.1, U6.5 (SW)
/CC1101_CSN: TP7.1, U1.33 (IO21), U2.7 (~CSn)
/CC1101_DCOUPL: C30.1, U2.5 (DCOUPL)
/CC1101_GDO0: TP8.1, U1.11 (IO26), U2.6 (GDO0)
/CC1101_GDO2: TP9.1, U1.12 (IO27), U2.3 (GDO2)
/CC1101_RBIAS: R30.1, U2.17 (RBIAS)
/CC1101_RF_N: C40.1, C42.1, U2.13 (RF_N)
/CC1101_RF_P: C41.1, C42.2, U2.12 (RF_P)
/CC1101_XOSC_Q1: C31.1, U2.8 (XOSC_Q1), Y1.1 (XTAL1)
/CC1101_XOSC_Q2: C32.1, U2.10 (XOSC_Q2), Y1.3 (XTAL2)
/CHASSIS: C5.1, J1.SH (SHIELD), R4.1
/CP2102_RST_N: R3.1, U5.9 (~RST)
/ESP_EN: C10.1, Q1.3 (C), R10.1, SW1.1, U1.3 (EN)
/ESP_IO0: Q2.3 (C), R11.1, SW2.1, U1.25 (IO0)
/EXP_GPIO13: J3.4, U1.16 (IO13)
/EXP_GPIO14: J3.5, U1.13 (IO14)
/EXP_GPIO22: J3.8, U1.36 (IO22)
/EXP_GPIO34: J3.9, U1.6 (IO34)
/EXP_GPIO35: J3.10, U1.7 (IO35)
/GND: B1.2 (GND), C1.2, C2.2, C3.2, C4.2, C5.2, C6.2, C7.2, C8.2, C9.2, C10.2, C11.2, C12.2, C13.2, C20.2, C21.2, C22.2, C23.2, C24.2, C25.2, C26.2, C30.2, C31.2, C32.2, C43.2, C44.2, C45.2, C46.2, C47.2, C48.2, C49.2, C50.2, C51.2, C52.2, C53.2, C54.2, C60.2, C61.2, C70.2, C71.2, D1.2 (GND), D2.2 (A), D3.1 (K), D4.1 (K), D5.2 (A2), J1.A1 (GND), J1.A12 (GND), J1.B1 (GND), J1.B12 (GND), J2.2 (Ext), J3.3, PWR1.1, R1.2, R2.2, R4.2, R6.2, R30.2, R60.2, R61.2, R70.2, R71.2, SW1.2, SW2.2, TP1.1, U1.1, U1.15, U1.38, U1.39, U1.[1,15,38,39] (GND), U2.16 (GND), U2.19 (GND), U2.21 (EP_GND), U3.1 (GND), U3.2 (GND), U3.3 (GND), U3.4 (GND), U3.6 (GND), U3.7 (GND), U3.9 (GND), U3.10 (GND), U3.12 (GND), U3.13 (GND), U3.15 (GND), U3.20 (VSS_EXT), U3.21 (GND), U3.23 (GND), U3.24 (GND), U3.25 (EP_GND), U4.1 (GND), U4.2 (GND), U4.3 (GND), U4.4 (GND), U4.6 (GND), U4.7 (GND), U4.9 (GND), U4.10 (GND), U4.12 (GND), U4.13 (GND), U4.15 (GND), U4.20 (VSS_EXT), U4.21 (GND), U4.23 (GND), U4.24 (GND), U4.25 (EP_GND), U5.2 (GND), U5.25 (GND), U6.4 (GND), U7.2 (GND), U8.1 (~1OE), U8.4 (GND), U8.7 (~2OE), Y1.2 (GND), Y1.4 (GND)
/MAIN_POWER_EN: J4.2, R71.1, U7.3 (ON)
/POWER_LED_A: D4.2 (A), R13.2
/POWER_SLEW: C70.1, U7.4 (CT)
/RF315_A: L42.2, L43.1, L45.1
/RF315_B: C46.1, L43.2, L44.1
/RF315_TRAP: C45.1, L45.2
/RF433_A: C47.1, L46.2, L47.1
/RF433_B: C48.1, L47.2, L48.1
/RF433_C: C49.1, L48.2, L49.1
/RF868_A: C50.1, L50.2, L51.1
/RF868_B: C51.1, L51.2, U4.14 (RF1)
/RF_315_IN: L42.1, U3.14 (RF1)
/RF_315_OUT: L44.2, U4.8 (RF3)
/RF_433_IN: L46.1, U3.11 (RF2)
/RF_433_OUT: L49.2, U4.11 (RF2)
/RF_868_915_IN: L50.1, U3.8 (RF3)
/RF_COMBINED: C52.1, L52.1, U4.22 (RFC)
/RF_DISABLE: R33.1, U1.26 (IO4), U3.19 (V3), U4.19 (V3)
/RF_FEED: C53.1, L52.2, R41.1
/RF_OUT0: J3.6, R34.1, U1.27 (IO16), U4.17 (V1)
/RF_OUT1: J3.7, R35.1, U1.28 (IO17), U4.18 (V2)
/RF_SMA: C54.1, D5.1 (A1), J2.1 (In), R41.2
/RF_SW0: R31.1, TP10.1, U1.8 (IO32), U3.17 (V1)
/RF_SW1: R32.1, TP11.1, U1.9 (IO33), U3.18 (V2)
/RF_SWITCH_IN: C44.1, L41.2, U3.22 (RFC)
/SPI_MISO: TP5.1, U1.31 (IO19), U2.2 (SO_GDO1)
/SPI_MOSI: TP6.1, U1.37 (IO23), U2.20 (SI)
/SPI_SCLK: TP4.1, U1.30 (IO18), U2.1 (SCLK)
/STATUS_LED: R12.1, U1.10 (IO25)
/STATUS_LED_A: D3.2 (A), R12.2
/U3_RF4_TERM: R60.1, U3.5 (RF4)
/U4_RF4_TERM: R61.1, U4.5 (RF4)
/UART_RX_ESP: U1.34 (RXD0/IO3), U8.6 (1Y)
/UART_RX_USB: U5.20 (RXD), U8.3 (2Y)
/UART_TX_ESP: TP12.1, U1.35 (TXD0/IO1), U8.5 (2A)
/UART_TX_USB: U5.21 (TXD), U8.2 (1A)
/USB_ACTIVE: J4.1, R70.1, U5.15 (~SUSPEND)
/USB_CC1: J1.A5 (CC1), R1.1
/USB_CC2: J1.B5 (CC2), R2.1
/USB_DM: D1.4 (I/O2), U5.4 (D-)
/USB_DM_CONN: D1.3 (I/O2), J1.A7 (D-), J1.B7 (D-)
/USB_DP: D1.6 (I/O1), U5.3 (D+)
/USB_DP_CONN: D1.1 (I/O1), J1.A6 (D+), J1.B6 (D+)
/USB_VBUS_SENSE: R5.2, R6.1, U5.8 (VBUS)
/VBUS_IN: F1.1, J1.A4 (VBUS), J1.A9 (VBUS), J1.B4 (VBUS), J1.B9 (VBUS)
/VBUS_PROTECTED: C7.1, C9.1, D1.5 (VBUS), D2.1 (K), F1.2, J3.2, PWR2.1, R5.1, TP2.1, U5.7 (VREGIN), U7.1 (VIN)
/VBUS_SWITCHED: C1.1, U6.2 (EN), U6.3 (VIN), U7.5 (QOD), U7.6 (VOUT)

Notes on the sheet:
USB-C INPUT, PROTECTION, AND 3.3 V POWER
J4: ship UNJUMPERED. Configure CP2102N for 500mA before AUTO (1-2). EXT (2-3) only with a known adequate 5V source; no USB power negotiation.
USB-UART AND PROGRAMMING
ESP32-WROOM-32E
CC1101 CORE - NAMED ELECTRICAL PINS
MULTIBAND RF PATH - REFERENCE VALUES; VNA TUNING REQUIRED
RF VALUES ABOVE ARE STARTING VALUES FROM M5STACK CAP CC1101 REV 0.3, NOT A TUNE CERTIFICATE. Do not order until custom RF footprints, placement, impedance geometry, and peer review are complete.
REV A ARCHITECTURE CHECKPOINT Transmit disabled by default. Use the correct removable antenna for each band. Regulatory limits depend on region, modulation, power, and application.
BRING-UP TEST POINTS

Board: 4 copper layers, 121 parts (0 on the bottom side), 79 nets, no tracks yet.

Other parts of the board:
MH1, MH2, MH3, MH4: MountingHole_2.7mm_M2.5

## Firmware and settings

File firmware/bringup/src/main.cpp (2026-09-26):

#include <Arduino.h>
#include <SPI.h>
#include "radio_diagnostics.h"
#include "rf_boot.h"

namespace Pins {
constexpr uint8_t kSclk = 18, kMiso = 19, kMosi = 23, kChipSelect = 21;
constexpr uint8_t kGdo0 = 26, kGdo2 = 27;
constexpr uint8_t kStatusLed = 25;
}

struct RfPins {
  void high(uint8_t pin) { digitalWrite(pin,HIGH); }
  void output(uint8_t pin) { pinMode(pin,OUTPUT); }
};

SPIClass radioSpi(VSPI);
struct RadioHal {
  void beginResetPins() {
    radioSpi.end();
    digitalWrite(Pins::kSclk, HIGH);
    digitalWrite(Pins::kMosi, LOW);
    pinMode(Pins::kSclk, OUTPUT);
    pinMode(Pins::kMosi, OUTPUT);
  }
  void endResetPins() {
    radioSpi.begin(Pins::kSclk, Pins::kMiso, Pins::kMosi, Pins::kChipSelect);
  }
  void beginTransaction() {
    radioSpi.beginTransaction(SPISettings(1000000, MSBFIRST, SPI_MODE0));
  }
  void endTransaction() { radioSpi.endTransaction(); }
  void chipSelect(bool selected) {
    digitalWrite(Pins::kChipSelect, selected ? LOW : HIGH);
  }
  uint8_t transfer(uint8_t value) { return radioSpi.transfer(value); }
  bool ready() { return digitalRead(Pins::kMiso) == LOW; }
  uint32_t nowUs() { return micros(); }
  void delayUs(uint32_t value) { delayMicroseconds(value); }
  void isolateRf() {
    RfPins pins;
    RfBoot::isolate(pins);
    delayMicroseconds(10);
  }
};

void setup() {
  // A3 ONLY: PE42442 V3/V2/V1=111 is all-off. External pullups protect
  // RF selection during reset/boot, before firmware has executed.
  digitalWrite(Pins::kChipSelect, HIGH);
  pinMode(Pins::kChipSelect, OUTPUT);
  RfPins rfPins;
  RfBoot::begin(rfPins);
  digitalWrite(Pins::kStatusLed, LOW);
  pinMode(Pins::kStatusLed, OUTPUT);
  pinMode(Pins::kGdo0, INPUT);
  pinMode(Pins::kGdo2, INPUT);
  digitalWrite(Pins::kSclk, LOW);
  digitalWrite(Pins::kMosi, LOW);
  pinMode(Pins::kSclk, OUTPUT);
  pinMode(Pins::kMosi, OUTPUT);

  Serial.begin(115200);
  delay(300);
  Serial.println("ESP32 + CC1101 A3 digital diagnostics v3 (PE42442)");
  radioSpi.begin(Pins::kSclk, Pins::kMiso, Pins::kMosi, Pins::kChipSelect);
  RadioHal hal;
  Diagnostics::Radio<RadioHal> radio(hal);
  const auto result = radio.run();
  Serial.printf("RESULT=%s PARTNUM=0x%02X VERSION=0x%02X MARCSTATE=0x%02X\n",
                Diagnostics::errorName(result.error), result.part,
                result.version, result.state);
  digitalWrite(Pins::kStatusLed, result.ok() ? HIGH : LOW);
  Serial.println("RF paths remain isolated. No RX/TX profile or command issued.");
  Serial.println("Digital check only; this is not RF or board qualification.");
}

void loop() { delay(1000); }

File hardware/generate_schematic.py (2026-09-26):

#!/usr/bin/env python3
"""Generate the Rev A architecture schematic.

The RF topology and starting values follow the published M5Stack Cap CC1101
Rev 0.3 reference schematic. They are captured as a reproducible design basis,
not treated as proof that a different PCB layout is already tuned. Exact RF
footprints, placement, controlled impedance, and bench/VNA validation remain
pre-order gates. The generated schematic is therefore NOT an order candidate.
"""

from pathlib import Path

import kicad_sch_api as ksa
from kicad_sch_api.library.cache import get_symbol_cache
from kicad_sch_api.core.pin_utils import get_component_pin_info
from generate_symbols import main as generate_symbols


HERE = Path(__file__).resolve().parent
OUTPUT = HERE / "esp32-cc1101-multiband.kicad_sch"


def add(sch, lib_id, ref, value, x, y, footprint=None, **props):
    return sch.components.add(
        lib_id,
        reference=ref,
        value=value,
        position=(x, y),
        footprint=footprint,
        **props,
    )


def label(sch, ref, pin, net):
    # Explicit outward stubs keep net names outside IC bodies. The library's
    # pin-label convenience method places names over the pin names in KiCad 10.
    comp=sch.components.get(ref)
    pos, angle=get_component_pin_info(comp,str(pin))
    length=3.81 if ref.startswith(('U','J','B','Y')) else 0
    if ref=='J1': length=0  # Dense symbol has intersecting alternate-pin stubs.
    dx,dy={0:(-length,0),90:(0,length),180:(length,0),270:(0,-length)}[int(angle)%360]
    endpoint=(pos.x+dx,pos.y+dy)
    if length: sch.add_wire((pos.x,pos.y),endpoint)
    sch.labels.add(net,endpoint,rotation=0,size=.85,
                   justify_h='right' if dx<0 else 'left',justify_v='bottom')


def labels(sch, ref, mapping):
    for pin, net in mapping.items():
        label(sch, ref, pin, net)


def nc(sch, ref, pin):
    pos = sch.get_component_pin_position(ref, str(pin))
    if pos is not None:
        sch.no_connects.add(pos)


def passive_to_nets(sch, lib_id, ref, value, x, y, net1, net2, footprint):
    add(sch, lib_id, ref, value, x, y, footprint)
    labels(sch, ref, {"1": net1, "2": net2})


def main():
    get_symbol_cache().add_library_path(generate_symbols())
    sch = ksa.create_schematic("ESP32 CC1101 Multiband Rev A")
    sch.set_paper_size("A2")
    sch.set_title_block(
        title="ESP32-WROOM-32E + CC1101 Multiband",
        date="2026-09-26",
        rev="A3 DRAFT",
        company="Personal prototype",
        comments={
            1: "NOT FOR MANUFACTURE - RF footprints/layout/tuning pending verification",
            2: "USB-C power/programming; software-selected 315/433/868/915 MHz",
        },
    )

    # ------------------------------------------------------------------ USB
    sch.add_text("USB-C INPUT, PROTECTION, AND 3.3 V POWER", (60, 18), size=2.0)
    add(
        sch,
        "Connector:USB_C_Receptacle_USB2.0_16P",
        "J1",
        "USB-C USB2.0",
        40,
        60,
        "Connector_USB:USB_C_Receptacle_HRO_TYPE-C-31-M-12",
    )
    labels(
        sch,
        "J1",
        {
            "A1": "GND", "A4": "VBUS_IN", "A5": "USB_CC1",
            "A6": "USB_DP_CONN", "A7": "USB_DM_CONN", "A9": "VBUS_IN",
            "A12": "GND", "B1": "GND", "B4": "VBUS_IN",
            "B5": "USB_CC2", "B6": "USB_DP_CONN", "B7": "USB_DM_CONN",
            "B9": "VBUS_IN", "B12": "GND", "SH": "CHASSIS",
        },
    )
    nc(sch, "J1", "A8")
    nc(sch, "J1", "B8")

    passive_to_nets(
        sch, "Device:R", "R1", "5.1k 1%", 75, 45,
        "USB_CC1", "GND", "Resistor_SMD:R_0603_1608Metric"
    )
    passive_to_nets(
        sch, "Device:R", "R2", "5.1k 1%", 75, 55,
        "USB_CC2", "GND", "Resistor_SMD:R_0603_1608Metric"
    )
    passive_to_nets(
        sch, "Device:R", "R4", "1M", 75, 75,
        "CHASSIS", "GND", "Resistor_SMD:R_0603_1608Metric"
    )
    passive_to_nets(
        sch, "Device:C", "C5", "4.7nF 1kV", 75, 87,
        "CHASSIS", "GND", "Capacitor_SMD:C_1206_3216Metric"
    )
    add(
        sch, "Power_Protection:USBLC6-2SC6", "D1", "USBLC6-2SC6",
        95, 72, "Package_TO_SOT_SMD:SOT-23-6"
    )
    labels(
        sch,
        "D1",
        {"1": "USB_DP_CONN", "6": "USB_DP", "3": "USB_DM_CONN",
         "4": "USB_DM", "2": "GND", "5": "VBUS_PROTECTED"},
    )
    passive_to_nets(
        sch, "Device:Polyfuse", "F1", "750mA PTC", 95, 35,
        "VBUS_IN", "VBUS_PROTECTED", "Fuse:Fuse_1206_3216Metric"
    )
    passive_to_nets(
        sch, "Device:D_Zener", "D2", "PESD5V0S1UL", 115, 35,
        "VBUS_PROTECTED", "GND", "Diode_SMD:D_SOD-882"
    )
    add(
        sch, "ESP32_CC1101:AP63203", "U6", "AP63203WU-7",
        145, 45, "ESP32_CC1101_RF:Diodes_TSOT26"
    )
    labels(sch, "U6", {"1": "+3V3", "2": "VBUS_SWITCHED", "3": "VBUS_SWITCHED",
                        "4": "GND", "5": "BUCK_SW", "6": "BUCK_BST"})
    passive_to_nets(sch, "Device:L", "L1", "4.7uH XAL4030", 170, 35,
                    "BUCK_SW", "+3V3", "Inductor_SMD:L_Coilcraft_XAL4030-XXX")
    passive_to_nets(sch, "Device:C", "C13", "22uF 25V", 180, 65,
                    "+3V3", "GND", "Capacitor_SMD:C_1206_3216Metric")
    passive_to_nets(sch, "Device:C", "C14", "100nF", 170, 50,
                    "BUCK_BST", "BUCK_SW", "Capacitor_SMD:C_0402_1005Metric")
    add(sch, "ESP32_CC1101:TPS22918", "U7", "TPS22918DBVR", 430, 45,
        "Package_TO_SOT_SMD:SOT-23-6")
    labels(sch, "U7", {"1":"VBUS_PROTECTED", "2":"GND", "3":"MAIN_POWER_EN",
                        "4":"POWER_SLEW", "5":"VBUS_SWITCHED", "6":"VBUS_SWITCHED"})
    passive_to_nets(sch, "Device:C", "C70", "10nF", 460, 40,
                    "POWER_SLEW", "GND", "Capacitor_SMD:C_0402_1005Metric")
    passive_to_nets(sch, "Device:R", "R70", "10k", 460, 55,
                    "USB_ACTIVE", "GND", "Resistor_SMD:R_0603_1608Metric")
    passive_to_nets(sch, "Device:R", "R71", "100k", 460, 70,
                    "MAIN_POWER_EN", "GND", "Resistor_SMD:R_0603_1608Metric")
    add(sch, "Connector_Generic:Conn_01x03", "J4", "POWER ARM AUTO / EXT", 430, 83,
        "Connector_PinHeader_2.54mm:PinHeader_1x03_P2.54mm_Vertical")
    labels(sch, "J4", {"1":"USB_ACTIVE", "2":"MAIN_POWER_EN", "3":"+3V3_USB"})
    sch.add_text("J4: ship UNJUMPERED. Configure CP2102N for 500mA before AUTO (1-2).\nEXT (2-3) only with a known adequate 5V source; no USB power negotiation.", (405, 105), size=1)
    passive_to_nets(
        sch, "Device:C", "C1", "22uF 25V", 130, 65,
        "VBUS_SWITCHED", "GND", "Capacitor_SMD:C_1206_3216Metric"
    )
    passive_to_nets(
        sch, "Device:C", "C2", "22uF 25V", 160, 65,
        "+3V3", "GND", "Capacitor_SMD:C_1206_3216Metric"
    )
    for ref, net, x in (("PWR1", "GND", 135),
                        ("PWR2", "VBUS_PROTECTED", 145),
                        ("PWR3", "+3V3_RF", 155), ("PWR4", "+3V3_USB", 165),
                        ("PWR5", "+3V3", 175)):
        add(sch, "power:PWR_FLAG", ref, "PWR_FLAG", x, 82, None)
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

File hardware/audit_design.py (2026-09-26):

#!/usr/bin/env python3
"""Targeted regression checks; not a substitute for ERC/DRC or RF validation.

Run with KiCad's bundled Python after regenerating schematic, XML, PCB and BOM.
Checks the generated artifacts, not just the generator's intended assignments.
"""
import csv
import argparse
import json
import math
from pathlib import Path
import xml.etree.ElementTree as ET

import pcbnew

HERE = Path(__file__).resolve().parent


def main():
    parser=argparse.ArgumentParser(description=__doc__)
    parser.add_argument('--output',type=Path,default=HERE.parent/'reports/design-audit.json')
    args=parser.parse_args()
    root = ET.parse(HERE / "esp32-cc1101-multiband.xml").getroot()
    board = pcbnew.LoadBoard(str(HERE / "A3-routing-candidate.kicad_pcb"))
    placement = pcbnew.LoadBoard(str(HERE / "esp32-cc1101-multiband.kicad_pcb"))
    footprints = {f.GetReference(): f for f in board.GetFootprints()}
    comps = {c.attrib["ref"]: c for c in root.findall("components/comp")
             if c.findtext("footprint", "")}
    nets = {}
    for net in root.findall("nets/net"):
        for node in net.findall("node"):
            nets[(node.attrib["ref"], node.attrib["pin"])] = net.attrib["name"]
    checks = []
    measurements = {}

    def check(condition, description):
        checks.append({"check": description, "pass": bool(condition)})

    def net_is(ref, pin, expected):
        check(nets.get((ref, str(pin))) == "/" + expected,
              f"{ref}.{pin} -> {expected}")

    def pad(ref, pin):
        return next(p for p in footprints[ref].Pads() if p.GetNumber() == str(pin))

    def xy(item):
        pos = item.GetPosition()
        return pcbnew.ToMM(pos.x), pcbnew.ToMM(pos.y)

    def distance(a, b):
        ax, ay = xy(a)
        bx, by = xy(b)
        return math.hypot(ax - bx, ay - by)

    for pin in (4, 9, 11, 14, 15, 18):
        net_is("U2", pin, "+3V3_RF")
    for pin in (16, 19, 21):
        net_is("U2", pin, "GND")
    net_is("U2", 5, "CC1101_DCOUPL")
    for pin in (5, 6):
        net_is("U5", pin, "+3V3_USB")
    net_is("U5", 7, "VBUS_PROTECTED")
    net_is("U5", 15, "USB_ACTIVE")
    net_is("U5", 20, "UART_RX_USB")
    net_is("U5", 21, "UART_TX_USB")
    net_is("U5", 8, "USB_VBUS_SENSE")
    for ref, p1, p2, value in (
        ("R5", "VBUS_PROTECTED", "USB_VBUS_SENSE", "22.1k 1%"),
        ("R6", "USB_VBUS_SENSE", "GND", "47.5k 1%"),
    ):
        net_is(ref, 1, p1)
        net_is(ref, 2, p2)
        check(comps[ref].findtext("value") == value, f"{ref} divider value {value}")
    for ref, positive in (("D3", "STATUS_LED_A"), ("D4", "POWER_LED_A")):
        net_is(ref, 1, "GND")
        net_is(ref, 2, positive)
    net_is("D2", 1, "VBUS_PROTECTED")
    net_is("D2", 2, "GND")
    check(comps["D2"].findtext("footprint") == "Diode_SMD:D_SOD-882",
          "PESD5V0S1UL uses SOD-882")
    check(comps["U6"].findtext("value") == "AP63203WU-7",
          "Regulator is fixed 3.3 V AP63203")
    for pin, net in ((1, "+3V3"), (2, "VBUS_SWITCHED"), (3, "VBUS_SWITCHED"),
                     (4,"GND"),(5,"BUCK_SW"),(6,"BUCK_BST")):
        net_is("U6", pin, net)
    check(comps["U6"].findtext("footprint") == "ESP32_CC1101_RF:Diodes_TSOT26",
          "Buck uses manufacturer TSOT26 land pattern")
    for ref, pins in {
        'U7': {1:'VBUS_PROTECTED',2:'GND',3:'MAIN_POWER_EN',4:'POWER_SLEW',5:'VBUS_SWITCHED',6:'VBUS_SWITCHED'},
        'U8': {1:'GND',2:'UART_TX_USB',3:'UART_RX_USB',4:'GND',5:'UART_TX_ESP',6:'UART_RX_ESP',7:'GND',8:'+3V3'},
        'L1': {1:'BUCK_SW',2:'+3V3'}, 'C14': {1:'BUCK_BST',2:'BUCK_SW'},
        'C70': {1:'POWER_SLEW',2:'GND'}, 'R70': {1:'USB_ACTIVE',2:'GND'},
        'R71': {1:'MAIN_POWER_EN',2:'GND'}, 'J4': {1:'USB_ACTIVE',2:'MAIN_POWER_EN',3:'+3V3_USB'},
    }.items():
        for pin, net in pins.items(): net_is(ref,pin,net)
    for ref in ('C1','C2','C13'):
        check(comps[ref].findtext('value') == '22uF 25V' and
              comps[ref].findtext('footprint') == 'Capacitor_SMD:C_1206_3216Metric',
              ref+' high-voltage 1206 capacitor selected for DC-bias margin')
    for ref, signal in [('R31','RF_SW0'),('R32','RF_SW1'),('R33','RF_DISABLE'),
                        ('R34','RF_OUT0'),('R35','RF_OUT1')]:
        check({nets.get((ref,'1')),nets.get((ref,'2'))} == {'/'+signal,'/+3V3_RF'},
              ref+' pulls '+signal+' HIGH at reset')
        check(comps[ref].findtext('value') == '10k pullup', ref+' uses 10k, not weak 100k pullup')

    for ref in ("U3", "U4"):
        for pin, net in ((16, "+3V3_RF"), (17, "RF_SW0" if ref=='U3' else 'RF_OUT0'),
                         (18, "RF_SW1" if ref=='U3' else 'RF_OUT1'), (19,'RF_DISABLE'), (20,'GND'),(25,'GND')):
            net_is(ref, pin, net)
        check(comps[ref].findtext('value') == 'PE42442A-Z',ref+' 30 MHz-6 GHz specified switch')
    for ref,pins in {'U3':{14:'RF_315_IN',11:'RF_433_IN',8:'RF_868_915_IN',22:'RF_SWITCH_IN'},
                     'U4':{8:'RF_315_OUT',11:'RF_433_OUT',14:'RF868_B',22:'RF_COMBINED'}}.items():
        for pin,net in pins.items(): net_is(ref,pin,net)
    for ref in ("C3", "C4", "C6", "C8", "C7", "C9", "C11", "C12", "C71"):
        net_is(ref, 1, "+3V3_USB" if ref in ('C3','C4','C6','C8') else
               'VBUS_PROTECTED' if ref in ('C7','C9') else '+3V3')
        net_is(ref, 2, "GND")
    check('DNP' in comps['C8'].findtext('value'),'C8 omitted to limit attach-time capacitance')
    for ref in ("C21", "C22", "C23", "C24", "C25", "C26", "C60", "C61"):
        net_is(ref, 1, "+3V3_RF")
        net_is(ref, 2, "GND")
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

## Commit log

2026-09-22 Publish A2 engineering draft with design views, roadmap, licensing and AI disclosure
    [A2-routing-candidate.kicad_pcb, bom-draft.csv, esp32-cc1101-multiband.kicad_pcb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]
2026-09-24 Harden CC1101 bring-up and add fresh prototype preflight checks
2026-09-26 Develop A3 routed prototype candidate with power and RF redesign
    [A3-before-local-finishing.kicad_pcb, A3-critical-routes.kicad_pcb, A3-routing-candidate.kicad_pcb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]
2026-09-26 Refine crystal routing and add automated route margin checks
    [A3-before-crystal-refinement.kicad_pcb]
